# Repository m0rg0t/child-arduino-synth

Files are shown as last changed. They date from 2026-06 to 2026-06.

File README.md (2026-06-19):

# Child Buzzer Synth

A simple 7-key mini-piano toy for a child, built on an Arduino Nano with a
KY-006 passive buzzer. Seven keys play a C-major scale, a knob shifts the
octave, and a "squeeze both ends" gesture toggles a vibrato wobble.

Design spec: `docs/superpowers/specs/`. Wiring: `WIRING.md`. Enclosure models:
`stl/`.

## Firmware

- Sketch: `firmware/child_buzzer/child_buzzer.ino`
- Tunables (pins, note table, octaves, timings, vibrato, DEBUG):
  `firmware/child_buzzer/config.h`

### Flashing with the Arduino IDE

1. Open `firmware/child_buzzer/child_buzzer.ino`.
2. Tools → Board → **Arduino Nano**.
3. Tools → Processor → **ATmega328P** (or **"ATmega328P (Old Bootloader)"** for clones).
4. Tools → Port → your Nano's serial port.
5. Click **Upload (→)**.

### Flashing with arduino-cli

```bash
arduino-cli core install arduino:avr
arduino-cli compile --fqbn arduino:avr:nano firmware/child_buzzer
arduino-cli upload  --fqbn arduino:avr:nano:cpu=atmega328old -p /dev/cu.usbserial-XXXX firmware/child_buzzer
# Genuine Nanos (new bootloader): drop the :cpu=atmega328old suffix. Clone
# boards hang in avrdude sync without it.
```

## How to play

- **Press a key** → its note sounds while held (one note at a time; newest key wins).
- **Turn the knob** → shifts all keys up/down by octaves (deep ↔ squeaky) in Piano
  and Echo modes; controls tempo in Songs mode.

## Modes & gestures

Hold two keys for ~0.6 s to trigger a gesture (the held keys stay silent during the hold):

| Keys | Gesture | Feedback |
|---|---|---|
| 1 + 7 (ends) | toggle vibrato | rising chirp |
| 2 + 6 | toggle pentatonic scale | falling chirp  |
| 3 + 5 | next mode | 1–4 beeps = current mode |

Modes (announced by beep count when you cycle into them):

1. **Piano** — the classic 7-key C-major piano; knob = octave.
2. **FX** — each key is a sound effect: siren, laser, slide whistle, UFO,
   alarm, bird, robot.
3. **Songs** — each key plays a melody (key 1 = Twinkle Twinkle Little Star,
   key 2 = Mary Had a Little Lamb, key 3 = Ode to Joy, key 4 = a pop-ballad
   chorus hook, key 5 = the full pop ballad (verse → pre-chorus → chorus),
   key 6 = a hard-rock riff, key 7 = a stadium stomp-and-chant); knob = tempo;
   press the same key again to stop.
4. **Echo** — play something, pause 1.5 s, and the toy parrots it back.

Vibrato works in every mode; pentatonic changes the keyboard notes (Piano and
Echo). The knob sets the octave in Piano and Echo, and the tempo in Songs.

## Roadmap

- v2: line/aux audio output jack (design + parts list in the spec appendix).

## License

Released under the [MIT License](LICENSE) — free to use, modify, and build on
with attribution.

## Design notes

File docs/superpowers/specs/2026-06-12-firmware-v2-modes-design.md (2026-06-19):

# Child-buzzer firmware v2 — play modes

**Date:** 2026-06-12
**Status:** Implemented & verified on hardware (smoke test passed 2026-06-12; build 8138 B flash / 667 B SRAM)
**Builds on:** `docs/superpowers/specs/2026-06-03-child-buzzer-synth-design.md` (v1)

## Goal

Extend the 7-key mini-piano firmware with three new exclusive play modes (sound
effects, built-in songs, echo/parrot) plus a pentatonic scale toggle, all
switched by two-key hold combos in the spirit of the existing vibrato gesture.
No hardware changes: same 7 keys, octave knob, and KY-006 passive buzzer.

## Constraints (unchanged from v1)

- **Monophonic.** `tone()` owns the single hardware timer; one pitch at a time.
- **Integer-only math** in `loop()`; no floats.
- **Two-file split:** `config.h` holds all tunables/data, `child_buzzer.ino`
  holds all logic.
- ATmega328P: 32 KB flash, 2 KB SRAM. Song/FX data goes in `PROGMEM`.
- No automated tests; verification = `DEBUG` serial output + manual smoke test.

## Architecture

### The one-frequency contract

Every mode reduces to the contract the v1 piano already satisfies: *each tick,
produce one target frequency or −1 (silence).* All engines (piano,
FX sweep, song player, echo playback) feed the same final
`tone()`/`noTone()` write guarded by the `lastFreqWritten` dirty-flag.
Because the layering toggles (vibrato, pentatonic) act on that single
frequency path, they apply in every mode for free.

### Mode state machine

```c
enum Mode : uint8_t { MODE_PIANO, MODE_FX, MODE_SONG, MODE_ECHO };
```

- Default `MODE_PIANO` at power-up (no persistence across power cycles).
- Holding **keys 2+4** for `COMBO_HOLD_MS` cycles Piano → FX → Song → Echo →
  Piano. Entering mode *k* is announced with *k+1* short beeps (1 = Piano,
  4 = Echo). Beep announce may be briefly blocking, like v1 `chirp()`.
- Switching modes silences output and resets the engines (stops songs,
  clears the echo buffer, kills any running FX).

### Combo gestures (table-driven)

The v1 single-purpose `updateComboToggle` generalizes into a table of three
entries `{keyA, keyB, callback}`, each with its own edge-triggered hold state:

| Keys | Hold time | Action | Audio feedback |
|---|---|---|---|
| 0+6 (ends) | `COMBO_HOLD_MS` | toggle vibrato (v1, unchanged) | rising 2-beep chirp |
| 1+5 | `COMBO_HOLD_MS` | toggle pentatonic | falling 2-beep chirp |
| 2+4 | `COMBO_HOLD_MS` | cycle mode | N-beep mode announce |

While any combo pair is physically held, those keys are suppressed from note
playback. The v1 `suppressEnds` bool becomes a 7-bit suppression mask passed
to `activeNote()`.

### Orthogonal toggles

- **Vibrato (0+6):** v1 behavior, applies to the final frequency in any mode.
- **Pentatonic (1+5):** selects which 7-entry note table `noteFrequency()`
  reads. Second table in `config.h`: C-major pentatonic spanning into the
  next octave — `{262, 294, 330, 392, 440, 523, 587}` (C D E G A C′ D′).
  Octave doubling via `<< band` is unchanged. Affects piano/echo key input;
  songs and FX use their own pitch data and ignore it.

## Modes

### MODE_PIANO

Exactly v1 behavior (last-pressed-wins, knob = octave band), plus the new
toggles/combos above.

### MODE_FX — sound effects

Each key triggers one effect. All effects run on **one generic non-blocking
sweep engine**; an effect is a parameter row (stored in `config.h`):

```c
struct FxDef { uint16_t startHz, endHz; int16_t stepHz; uint8_t stepMs; uint8_t behavior; };
// behavior: FX_ONCE (play sweep once, then silence), FX_LOOP (wrap to start),
//           FX_PINGPONG (reverse at the ends)
```

Provisional key map (tunable):

| Key | Effect | Shape |
|-----|---|---|
| 0 | siren | slow PINGPONG, ~600–1200 Hz |
| 1 | laser zap | fast ONCE, high→low |
| 2 | slide whistle | medium ONCE, low→high |
| 3 | UFO warble | fast PINGPONG, narrow span |
| 4 | alarm | PINGPONG with step = full span (two-tone) |
| 5 | bird chirp | fast ONCE, short rising, retriggers while held |
| 6 | robot babble | LOOP with coarse steps across a wide span |

Effect sounds while the key is held; `FX_ONCE` runs to completion then goes
silent until re-press. Releasing the key silences immediately.
Last-pressed-wins applies, same as notes. The knob is unused in FX mode.

### MODE_SONG — built-in melodies

One melody per key, stored in `PROGMEM` as `{degree, duration}` pairs:

- `degree` = scale-degree index 0–6 into `NOTE_HZ` plus a small octave
  offset (packed in one byte; a sentinel value encodes a rest).
- `duration` = multiples of a base tick so the **knob controls tempo**
  (octave is meaningless mid-song; tempo is fun). Mapping: knob low = slow,
  high = fast, over a tunable BPM range.

Song list (key 0 → 6):

1. Twinkle Twinkle Little Star
2. Mary Had a Little Lamb
3. Ode to Joy
4. Pop-ballad chorus hook (see 2026-06-18-pop-ballad-song-design.md)
5. Full pop ballad — verse → pre-chorus → chorus
6. Hard-rock riff (the classic four-note figure)
7. Stadium stomp-and-chant hook (the stomp-stomp-clap rendered as low
   ~80–110 Hz thuds)

Note on the hard-rock riff: its intervals (0, +3, +5, +6 semitones)
are not playable from G in C major, but transposed to start on **B** they
land entirely on white keys: B–D–E | B–D–F–E | B–D–E | D–B. The
scale-degree encoding therefore needs no accidentals.

Interaction: pressing a key starts that song from the top; pressing a
*different* key switches songs; pressing the *same* key stops playback.
Playback is a non-blocking ticker in `loop()`. A song plays to its end and
stops (no looping).

### MODE_ECHO — record & parrot

The kid plays normally (full piano behavior, knob = octave, toggles apply)
while a recorder logs events:

```c
struct EchoEvent { uint8_t noteAndBand; uint16_t durationMs; uint16_t gapMs; };
// noteAndBand packs note index (low 3 bits) + octave band (next 2 bits)
// ECHO_MAX_EVENTS = 32  →  ~160 B of SRAM
```

- After `ECHO_SILENCE_MS` (default 1500 ms, tunable) with no key held and a
  non-empty buffer, the toy replays the recorded phrase (same notes,
  durations, and gaps, at the octave band captured per event... see below),
  then clears the buffer and is ready to record again.
- Recorded pitch: store the *final computed frequency band* alongside the
  note, i.e. record `{note, band}` at press time so knob twiddling during
  playback doesn't shift the parrot.
- Durations and gaps are clamped to `uint16_t` max (~65 s — far beyond toy
  attention spans).
- Buffer full → recording stops silently; the replay still happens at the
  silence timeout.
- Key presses during playback abort the replay and start a fresh recording.

## config.h additions (tunables/data only)

- `NOTE_HZ_PENTA[7]` second note table
- combo pair definitions + (existing) `COMBO_HOLD_MS`
- `FX_DEFS[7]` parameter rows + behavior enum constants
- `SONGS[7]` `PROGMEM` note tables + per-song lengths; tempo knob BPM range
- `ECHO_MAX_EVENTS`, `ECHO_SILENCE_MS`
- mode-announce beep pitch/duration

## child_buzzer.ino additions (logic only)

- `Mode` enum + mode cycle handling
- table-driven combo detector (replaces `updateComboToggle`)
- suppression mask in `activeNote()`
- FX sweep engine (one state struct: current Hz, direction, next-step time)
- song player ticker (current song, position, next-event time, tempo from knob)
- echo recorder + playback ticker
- `loop()` dispatches by mode to compute the tick's target frequency, then the
  existing shared vibrato + dirty-flag `tone()` write

## Error handling / edge cases

- Mode switch mid-sound: silence output, reset all engine state.
- Combo keys are suppressed as notes while held (existing v1 pattern).
- Blocking announce beeps (≤ ~500 ms) are acceptable, consistent with v1
  `chirp()`; `lastFreqWritten` is reset to −1 afterward.
- Echo buffer overflow: drop further events, keep what fits.
- All frequency math stays in `int32_t` intermediate / `uint16_t` result,
  as in v1.

## Verification (manual; no test harness)

Extend the `DEBUG` serial line with `mode=`. Smoke-test checklist:

1. Power-up → piano mode; v1 behaviors all intact (scale, octave knob,
   vibrato combo, debounce).
2. Hold 1+5 → falling chirp; keys now pentatonic; toggle back.
3. Hold 2+4 → 2 beeps → FX mode; each key produces its distinct effect;
   release silences; ONCE effects don't loop.
4. Hold 2+4 → 3 beeps → song mode; each key starts its song; same key stops;
   different key switches; knob audibly changes tempo; hard-rock
   riff recognizable.
5. Hold 2+4 → 4 beeps → echo mode; play a short phrase, wait ~1.5 s, hear it
   parroted back with timing; playing during replay interrupts it.
6. Hold 2+4 → 1 beep → back to piano.
7. Vibrato toggle works in every mode (wobbles songs/FX/echo playback).
8. Verify flash/SRAM usage in `arduino-cli compile` output stays comfortable
   (flash < 80%, SRAM < 50%).

## Out of scope

- Audio-jack line out (still deferred to v2 hardware, see v1 spec appendix).
- Mode persistence across power cycles (EEPROM) — not needed for a toy.
- Polyphony/arpeggio chords — cut during brainstorming.
- Games (Simon, follow-me teaching) — cut during brainstorming.

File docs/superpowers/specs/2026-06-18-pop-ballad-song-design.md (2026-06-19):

# Design: a pop ballad in song mode (two slots)

Date: 2026-06-18
Status: approved (design), pending on-device pitch verification

## Goal

Add a buzzer melody arrangement of a well-known pop ballad to **song mode**:

- **Key index 4** (the 5th physical key, README "key 5", currently *Frère
  Jacques*) → **full arrangement**: verse → pre-chorus → chorus, played once.
- **Key index 3** (the 4th physical key, README "key 4", currently *London
  Bridge*) → **short chorus hook** only.

*Frère Jacques* and *London Bridge* are displaced (removed). The other five
songs are unchanged.

## Constraints (from the existing hardware/firmware)

These are fixed by the toy and the song engine; the arrangement is built to fit
them, not the other way around:

1. **Monophonic.** One `tone()` voice → melody line only. No chords, no
   harmony, no accompaniment.
2. **White keys only.** A song note byte encodes a scale degree 0–6 into the
   major table `NOTE_HZ` (`C D E F G A B`) plus an octave band 0–3. There is no
   representation for sharps/flats. Any non-diatonic note in the source must be
   nudged to the nearest white key — the same approach already documented for
   the hard-rock riff song.
3. **No looping.** `songTick()` stops at the end of the table; a song plays once
   per press (press the same key again to stop early, a different key to
   switch).
4. **Knob = tempo.** `songTickMs()` maps the knob to 350 ms/tick (left, slow) …
   110 ms/tick (right, fast). A ballad sounds best toward the slow end. No
   per-song tempo storage — the player is tempo-agnostic.
5. **Data, not engine.** This is purely new `PROGMEM` tables + roster wiring.
   The song engine (`songTick`, `songLoadEvent`, `songNoteHz`, gaps, rests) is
   not modified.

## Musical approach

The ballad sits in a relative minor→major key pair (verse in a minor mode, the
chorus lifting to its relative major — one shared key signature). That maps
cleanly onto white keys by anchoring:

- **Verse** in **A natural minor** (`A B C D E F G` — all white keys),
- **Chorus** in its relative **C major** (`C D E F G A B` — all white keys).

So the bulk of the tune lands on white keys with no accidentals. The few
chromatic / raised-leading-tone moments get rounded to the nearest white key.
Octave placement: verse low (bands 0–1), pre-chorus rising, chorus up in bands
1–2 so the signature rising chorus hook reads clearly on the buzzer.

This is a **melodic reduction** — recognizable contour within the monophonic,
white-key, diatonic envelope — not a faithful reproduction of any recording.

## Data model (unchanged format)

Two new `PROGMEM` byte streams of `{note, duration}` pairs, same encoding as the
existing seven songs (`SN(deg, oct)`, `SONG_REST` for rests):

- `SONG_BALLAD[]` — verse + pre-chorus + chorus. Est. ~60–80 pairs
  (~120–160 B PROGMEM).
- `SONG_BALLAD_HOOK[]` — the chorus phrase only. Est. ~16–28 pairs.

Flash budget is a non-issue (32 KB part, current sketch is small; the v2 song
set added only ~250 B total).

## Files changed

- `firmware/child_buzzer/config.h`
  - Remove `SONG_LONDON[]` and `SONG_FRERE[]`.
  - Add `SONG_BALLAD_HOOK[]` (slot 3) and `SONG_BALLAD[]` (slot 4).
  - Update `SONGS[]`, `SONG_LEN[]`, and the per-key comments to the new roster.
- `README.md` — update the songs list (key 4 = pop-ballad chorus hook, key 5 =
  full pop ballad).
- `docs/superpowers/specs/2026-06-12-firmware-v2-modes-design.md` — update the
  song-list entries for keys 4 and 5 so the canonical reference stays accurate.

## Verification (empirical, on hardware)

There is no automated audio test; pitch correctness is verified by ear. The
Arduino is attached, so the loop is:

1. Transcribe → `arduino-cli compile --fqbn arduino:avr:nano`.
2. Flash with `cpu=atmega328old` (this board's old-bootloader requirement).
3. Cycle to song mode (hold keys 2+4 → 3 announce beeps).
4. Press key 4 (index 3) → short chorus hook; press key 5 (index 4) → full
   arrangement. Confirm both are recognizable; turn the knob to a slow tempo.
5. The user listens and flags any off notes; iterate on the tables and re-flash.

Acceptance: both keys play a recognizable rendition of the ballad, the full
version moves through verse → pre-chorus → chorus, tempo responds to the knob,
and the other five songs still play. Record the final compiled flash size.

## Out of scope

Chords/harmony (hardware can't), lyrics (note data only — no text reproduced),
looping, per-song tempo, and any change to the song engine or other modes.

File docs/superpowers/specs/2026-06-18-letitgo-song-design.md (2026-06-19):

# Design: "Let It Go" in song mode (two slots)

Date: 2026-06-18
Status: approved (design), pending on-device pitch verification

## Goal

Add a buzzer melody arrangement of *Let It Go* (Frozen) to **song mode**:

- **Key index 4** (the 5th physical key, README "key 5", currently *Frère
  Jacques*) → **full arrangement**: verse → pre-chorus → chorus, played once.
- **Key index 3** (the 4th physical key, README "key 4", currently *London
  Bridge*) → **short chorus hook** only.

*Frère Jacques* and *London Bridge* are displaced (removed). The other five
songs are unchanged.

## Constraints (from the existing hardware/firmware)

These are fixed by the toy and the song engine; the arrangement is built to fit
them, not the other way around:

1. **Monophonic.** One `tone()` voice → melody line only. No chords, no
   harmony, no accompaniment.
2. **White keys only.** A song note byte encodes a scale degree 0–6 into the
   major table `NOTE_HZ` (`C D E F G A B`) plus an octave band 0–3. There is no
   representation for sharps/flats. Any non-diatonic note in the source must be
   nudged to the nearest white key — the same approach already documented for
   *Smoke on the Water*.
3. **No looping.** `songTick()` stops at the end of the table; a song plays once
   per press (press the same key again to stop early, a different key to
   switch).
4. **Knob = tempo.** `songTickMs()` maps the knob to 350 ms/tick (left, slow) …
   110 ms/tick (right, fast). A ballad sounds best toward the slow end. No
   per-song tempo storage — the player is tempo-agnostic.
5. **Data, not engine.** This is purely new `PROGMEM` tables + roster wiring.
   The song engine (`songTick`, `songLoadEvent`, `songNoteHz`, gaps, rests) is
   not modified.

## Musical approach

*Let It Go* sits in a relative minor→major key pair (verse in a minor mode, the
chorus lifting to its relative major — one shared key signature). That maps
cleanly onto white keys by anchoring:

- **Verse** in **A natural minor** (`A B C D E F G` — all white keys),
- **Chorus** in its relative **C major** (`C D E F G A B` — all white keys).

So the bulk of the tune lands on white keys with no accidentals. The few
chromatic / raised-leading-tone moments get rounded to the nearest white key.
Octave placement: verse low (bands 0–1), pre-chorus rising, chorus up in bands
1–2 so the signature rising "let it go" sequence reads clearly on the buzzer.

This is a **melodic reduction** — recognizable contour within the monophonic,
white-key, diatonic envelope — not a faithful reproduction of the recording.

## Data model (unchanged format)

Two new `PROGMEM` byte streams of `{note, duration}` pairs, same encoding as the
existing seven songs (`SN(deg, oct)`, `SONG_REST` for rests):

- `SONG_LETITGO[]` — verse + pre-chorus + chorus. Est. ~60–80 pairs
  (~120–160 B PROGMEM).
- `SONG_LETITGO_HOOK[]` — the chorus phrase only. Est. ~16–28 pairs.

Flash budget is a non-issue (32 KB part, current sketch is small; the v2 song
set added only ~250 B total).

## Files changed

- `firmware/child_buzzer/config.h`
  - Remove `SONG_LONDON[]` and `SONG_FRERE[]`.
  - Add `SONG_LETITGO_HOOK[]` (slot 3) and `SONG_LETITGO[]` (slot 4).
  - Update `SONGS[]`, `SONG_LEN[]`, and the per-key comments to the new roster.
- `README.md` — update the songs list (key 4 = Let It Go hook, key 5 = Let It
  Go full).
- `docs/superpowers/specs/2026-06-12-firmware-v2-modes-design.md` — update the
  song-list entries for keys 4 and 5 so the canonical reference stays accurate.

## Verification (empirical, on hardware)

There is no automated audio test; pitch correctness is verified by ear. The
Arduino is attached, so the loop is:

1. Transcribe → `arduino-cli compile --fqbn arduino:avr:nano`.
2. Flash with `cpu=atmega328old` (this board's old-bootloader requirement).
3. Cycle to song mode (hold keys 2+4 → 3 announce beeps).
4. Press key 4 (index 3) → short chorus hook; press key 5 (index 4) → full
   arrangement. Confirm both are recognizable; turn the knob to a slow tempo.
5. The user listens and flags any off notes; iterate on the tables and re-flash.

Acceptance: both keys play a recognizable *Let It Go*, the full version moves
through verse → pre-chorus → chorus, tempo responds to the knob, and the other
five songs still play. Record the final compiled flash size.

## Out of scope

Chords/harmony (hardware can't), lyrics (note data only — no text reproduced),
looping, per-song tempo, and any change to the song engine or other modes.

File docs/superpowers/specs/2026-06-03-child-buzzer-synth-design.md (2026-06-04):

# Child Buzzer Synth — Design Spec

**Date:** 2026-06-03
**Status:** Approved (design); implementation pending
**v1 scope:** mini-piano + octave knob + vibrato. The line/aux audio jack is
**deferred to a later version** — its design is preserved in the appendix.

## Overview

A simple, sturdy mini-piano toy for a child. Seven keyboard switches play the
notes of a one-octave C-major scale through a KY-006 passive buzzer. A rotary
knob shifts the whole keyboard up or down by octaves (deep ↔ squeaky). A
software "squeeze both ends" gesture toggles a vibrato (pitch-wobble) effect.

A passive line/aux audio jack is planned for a later version (see appendix); v1
ships with the on-board buzzer only.

## Goals

- Intuitive for a small child: press a key → hear a note; turn the knob → pitch
  changes; no menus or screens.
- Pleasant, musical output (diatonic scale, in tune).
- Buildable from exactly the parts on hand — no extra components required.
- Firmware that is easy to re-tune (notes, octaves, timings, vibrato) without
  editing logic.

## Hardware / Bill of Materials

Exactly the parts already specified — nothing extra for v1:

| Qty | Part | Notes |
|----:|---|---|
| 1 | Arduino Nano | The brain |
| 7 | Keyboard switches (mechanical key switches) | One per piano key |
| 1 | Rotary angle sensor (analog potentiometer) | Octave knob — NOT an encoder |
| 1 | KY-006 passive piezo buzzer | Driven by `tone()` square wave |

The line/aux audio jack and its passives are listed in the appendix (deferred).

### Pin map

| Signal | Pin | Mode | Wiring |
|---|-----|---|---|
| Key 1 (C, lowest) | D2 | `INPUT_PULLUP` | switch other side → GND |
| Key 2 (D) | D3 | `INPUT_PULLUP` | switch → GND |
| Key 3 (E) | D4 | `INPUT_PULLUP` | switch → GND |
| Key 4 (F) | D5 | `INPUT_PULLUP` | switch → GND |
| Key 5 (G) | D6 | `INPUT_PULLUP` | switch → GND |
| Key 6 (A) | D7 | `INPUT_PULLUP` | switch → GND |
| Key 7 (B, highest) | D8 | `INPUT_PULLUP` | switch → GND |
| Buzzer | D9 | `OUTPUT` (`tone`) | KY-006 signal pin; GND to GND |
| Octave knob | A0 | analog in | pot wiper → A0; ends → 5V and GND |

`INPUT_PULLUP` means each switch only needs to connect its pin to GND when
pressed — no external resistors. A pressed key therefore reads `LOW`.

> **Audio jack:** deferred to a later version. The full circuit and parts list
> live in the appendix so the v1 build stays focused on the buzzer.

## Behavior

### 1. Mini-piano (free play)

- The 7 keys map to one octave of the **C-major scale**:
  `C D E F G A B` (do-re-mi-fa-sol-la-ti).
- **Sound while held:** pressing a key starts its note; releasing stops it.
- **Monophonic, last-pressed-wins:** only one note sounds at a time (single tone
  timer). The most recently pressed key that is still held is the one that
  sounds. When it is released, sound falls back to another currently-held key
  (most recent of those). When no key is held, the buzzer is silent (`noTone()`).
- Each key is **debounced** (~5 ms stable-state filter) to reject contact bounce.

### 2. Octave knob

- `analogRead(A0)` (0–1023) is mapped to **4 octave bands** (index 0–3):
  `band = (raw * 4) / 1024` → 0,1,2,3 across the knob's travel.
- Octave shift is applied by doubling frequency: `freq = noteHz[key] << band`.
  Doubling is exact and avoids floating-point math.
- Re-read every loop, so turning the knob **while holding a key** slides the
  pitch by whole octaves live.
- Base octave is C4: band 0 = C4 (262 Hz) … band 3 ≈ B7 (~3951 Hz) — squarely in
  the piezo's loudest range so even the lowest keys are clearly audible.

### 3. Vibrato toggle (software combo)

- **Gesture:** hold the **lowest + highest keys together** (Key 1 + Key 7) for
  **~600 ms** to toggle vibrato on/off.
- **Edge-triggered:** the toggle fires once when the combo is recognized, then
  will not fire again until both keys are released. This prevents rapid
  on/off flapping while the combo is held.
- During the combo, those two keys' **notes are suppressed** (no C/B note plays).
- On toggle, play a short **confirmation chirp** (e.g. two quick beeps) so the
  child gets feedback even though there is no screen.

### 4. Vibrato effect

- When **on**, the sounding note's pitch wobbles **±~4%** around the base note at
  **~6 Hz**.
- Implemented by re-calling `tone(BUZZER, modulatedFreq)` on a fixed update tick
  (e.g. every ~10 ms). `tone()` keeps the buzzer running on its timer; we just
  nudge the frequency on schedule.
- The wobble shape comes from a small **lookup table** (or triangle wave) to
  avoid slow floating-point `sin()` in the loop.
- When **off**, the note plays at a steady frequency.

## Firmware architecture

Approach A — single sketch + a hardware/config header:

- **`child_buzzer.ino`** — all logic:
  - `setup()` — configure pin modes.
  - `loop()` — orchestrate: read octave band, scan keys, detect combo, pick the
    active note, apply vibrato, drive `tone()` / `noTone()`.
  - `scanKeys()` — per-key debounce; maintain pressed state + press order.
  - `activeNoteIndex()` — apply last-pressed-wins to choose the sounding key
    (or none).
  - `readOctaveBand()` — knob → octave band 0–3.
  - `updateVibratoCombo()` — detect the both-ends hold, edge-triggered toggle,
    confirmation chirp.
  - `applyVibrato(baseFreq)` — return modulated frequency from the LUT when
    vibrato is on, else `baseFreq`.
- **`config.h`** — everything tweakable without touching logic:
  - Pin numbers (keys, buzzer, knob).
  - `noteHz[7]` — C-major base frequencies (octave 0 / C4).
  - `OCTAVE_BANDS` (default 4).
  - `VIBRATO_DEPTH_PCT` (~4), `VIBRATO_RATE_HZ` (~6), vibrato update interval.
  - `DEBOUNCE_MS` (~5), `COMBO_HOLD_MS` (~600).
  - `DEBUG` flag.
- **`WIRING.md`** — pin-by-pin connection table incl. the jack RC network.
- **`README.md`** — what it is + how to flash (Arduino IDE: select the Nano
  board + port, then upload).
- Existing **`stl/`** models and **`screenshoots/`** render are left untouched.

## Verification

Arduino firmware has no host test harness here; verification is debug output +
a manual smoke test.

- **`DEBUG` flag** prints to Serial: detected active key, octave band, computed
  frequency, and vibrato on/off state — so behavior is observable, not guessed.
- **Manual smoke-test checklist:**
  1. Each of the 7 keys sounds its own ascending note; releasing silences it.
  2. Pressing a new key while holding another switches to the new note;
     releasing it falls back to the still-held key.
  3. Turning the knob across its range shifts all keys through 4 octave bands.
  4. Holding both end keys ~600 ms plays the confirmation chirp and toggles
     vibrato; a single toggle per gesture (no flapping).
  5. With vibrato on, a held note audibly wobbles; with it off, the note is
     steady.

## Out of scope (possible future work)

- **Line/aux audio jack** — designed and parts-listed below; deferred to v2.
- Polyphony (would need more than the single tone timer).
- Selectable scales / instruments via the knob.
- Hardware vibrato switch or auto-mute switched jack.
- On-board amplifier for direct, loud headphone drive.

## Open tunables (decide during build by ear)

- Exact vibrato depth/rate (start ±4% / 6 Hz).
- Octave band base/range (start C4 → B7, 4 bands).
- Confirmation chirp pattern.

## Appendix — Line/aux audio jack (deferred to v2)

Passive add-on that hangs in parallel off the D9 tone signal — no firmware
change. Lets the toy feed powered speakers / an amp / aux-in while the on-board
buzzer keeps playing.

```
D9 ──[ ~1 kΩ ]──┬──[ 10 µF + ]──┬── Jack TIP ─┐
                │   (+ to D9)    │             ├─ tied together (mono → both ears)
              [10 kΩ]            └── Jack RING ┘
                │
               GND ───────────────────────────── Jack SLEEVE
```

- Coupling cap blocks the square wave's DC offset (no DC through the speaker).
- Series + shunt resistors attenuate the 5 V swing toward a safe line level and
  gently low-pass the square wave. Raise the series resistor to lower the level.
- Tip + ring tied so the mono tone reaches both channels.

### Parts to buy (jack add-on)

| # | Part | Spec to search for | Qty | Notes |
|---|---|---|----:|---|
| 1 | 3.5 mm stereo panel-mount jack (TRS, female) | "3.5mm stereo panel mount jack threaded nut" / PJ-392 | 1 | Threaded barrel + nut to screw into the enclosure hole. Confirm thread matches the hole (commonly 6 mm). |
| 2 | Coupling capacitor 10 µF | "10µF 25V electrolytic" (+ toward D9) **or** 1–10 µF film (non-polarized) | 1 | Rating ≥16 V. |
| 3 | Series resistor 1 kΩ | "1kΩ 1/4W 5%" | 1 | Current limit / attenuation. |
| 4 | Shunt resistor 10 kΩ | "10kΩ 1/4W 5%" | 1 | Sets DC level / divider to ground. |
| 5 | Hookup wire + heat-shrink (optional) | "22 AWG hookup wire", "2mm heat shrink" | — | Tidy solder joints to the jack lugs. |

Open tunable: jack attenuation — start 1 kΩ series / 10 kΩ shunt / 10 µF cap,
adjust series R by ear.

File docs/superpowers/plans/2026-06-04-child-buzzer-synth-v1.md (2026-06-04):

# Child Buzzer Synth v1 — Implementation Plan

> **For agentic workers:** REQUIRED SUB-SKILL: Use superpowers:subagent-driven-development (recommended) or superpowers:executing-plans to implement this plan task-by-task. Steps use checkbox (`- [ ]`) syntax for tracking.

**Goal:** Build the firmware for a 7-key mini-piano toy on an Arduino Nano: keys play a C-major scale through a KY-006 passive buzzer, a knob shifts the octave, and a "squeeze both ends" gesture toggles a vibrato wobble.

**Architecture:** A single Arduino sketch (`child_buzzer.ino`) with all hardware logic, plus a `config.h` holding every tunable (pins, note table, octave count, timings, vibrato, DEBUG). No external libraries — only the built-in `tone()`/`noTone()`, `digitalRead`, `analogRead`, `millis`. Monophonic output (one tone timer) with last-pressed-wins note selection. Verification is by clean compile + a manual hardware smoke test (no host test harness, per the approved spec).

**Tech Stack:** Arduino Nano (ATmega328P), Arduino C++, `tone()` square-wave output, internal pull-ups for switches, analog read for the potentiometer.

---

## File Structure

```
child-buzzer/                       (existing git repo)
├── firmware/
│   └── child_buzzer/               (Arduino sketch folder — name matches .ino)
│       ├── child_buzzer.ino        (all logic: setup, loop, keys, octave, vibrato)
│       └── config.h                (pins, note table, octaves, timings, vibrato, DEBUG)
├── WIRING.md                       (pin-by-pin connection guide)
├── README.md                       (what it is + how to flash + how to play)
├── docs/superpowers/...            (spec + this plan)
├── stl/                            (existing 3D models — untouched)
└── screenshoots/                   (existing render — untouched)
```

Responsibilities:
- **`config.h`** — the only file you edit to re-tune behavior. Pure constants.
- **`child_buzzer.ino`** — reads hardware, decides the active note, drives the buzzer.
- **`WIRING.md` / `README.md`** — build + usage docs.

## Compile verification (used by every code task)

Two options. Use whichever you have.

- **arduino-cli** (one-time setup `arduino-cli core install arduino:avr`):
  ```bash
  arduino-cli compile --fqbn arduino:avr:nano firmware/child_buzzer
  ```
  Expected: ends with `Sketch uses NNNN bytes ... Global variables use ...` and exit code 0. For old-bootloader clones the upload step later uses `--fqbn arduino:avr:nano:cpu=atmega328old`; the compile FQBN above is fine either way.
- **Arduino IDE:** open `firmware/child_buzzer/child_buzzer.ino`, click **Verify (✓)**. Expected: "Done compiling." with no errors.

---

### Task 1: Sketch scaffold — `config.h` + minimal compiling sketch

**Files:**
- Create: `firmware/child_buzzer/config.h`
- Create: `firmware/child_buzzer/child_buzzer.ino`

- [ ] **Step 1: Create `config.h` with all tunables**

```cpp
#ifndef CONFIG_H
#define CONFIG_H

#include <Arduino.h>

// ---- Pins ----
// 7 keyboard switches, lowest (C) -> highest (B). Each switch wired to GND,
// read with INPUT_PULLUP, so a pressed key reads LOW.
const uint8_t KEY_PINS[7] = { 2, 3, 4, 5, 6, 7, 8 };
const uint8_t BUZZER_PIN  = 9;     // KY-006 passive buzzer signal pin
const uint8_t KNOB_PIN    = A0;    // rotary angle sensor (potentiometer) wiper

// ---- Notes ----
// Base frequencies (Hz) for octave band 0 = C-major scale starting at C4.
// Index 0..6 = C D E F G A B. Higher octave bands multiply by 2 per band.
const uint16_t NOTE_HZ[7]  = { 262, 294, 330, 349, 392, 440, 494 };
const uint8_t  OCTAVE_BANDS = 4;   // knob selects band 0..3  (C4 .. ~B7)

// ---- Timing ----
const uint16_t DEBOUNCE_MS   = 5;    // per-key debounce window
const uint16_t COMBO_HOLD_MS = 600;  // hold both end keys this long to toggle vibrato

// ---- Vibrato ----
const uint16_t VIBRATO_DEPTH_PERMILLE = 40;  // +/-4.0% pitch wobble
const uint16_t VIBRATO_UPDATE_MS      = 10;  // how often to nudge the pitch
// 16 LUT steps * 10 ms = 160 ms per cycle ~= 6.25 Hz wobble.

// ---- Debug ----
#define DEBUG 0   // set to 1 to print state over Serial @115200

#endif // CONFIG_H
```

- [ ] **Step 2: Create minimal `child_buzzer.ino`**

```cpp
#include "config.h"

void setup() {
  for (uint8_t i = 0; i < 7; i++) {
    pinMode(KEY_PINS[i], INPUT_PULLUP);
  }
  pinMode(BUZZER_PIN, OUTPUT);
#if DEBUG
  Serial.begin(115200);
#endif
}

void loop() {
  // Behavior is added in later tasks.
}
```

- [ ] **Step 3: Verify it compiles**

Run: `arduino-cli compile --fqbn arduino:avr:nano firmware/child_buzzer` (or IDE Verify)
Expected: compiles cleanly, exit code 0.

- [ ] **Step 4: Commit**

```bash
git add firmware/child_buzzer/config.h firmware/child_buzzer/child_buzzer.ino
git commit -m "feat(fw): scaffold sketch with pin setup and tunable config.h"
```

---

### Task 2: Playable mono piano — keys, debounce, last-pressed-wins, octave knob

This is the mid-build hardware checkpoint: after this task you can flash it and play 7 notes across 4 octaves. No vibrato yet.

**Files:**
- Modify: `firmware/child_buzzer/child_buzzer.ino` (replace entire file)

- [ ] **Step 1: Replace `child_buzzer.ino` with the mono-piano version**

```cpp
#include "config.h"

// ---- Per-key debounce + press-order state ----
bool     keyHeld[7]      = { false, false, false, false, false, false, false };
bool     lastReading[7]  = { false, false, false, false, false, false, false };
uint32_t lastChangeMs[7] = { 0, 0, 0, 0, 0, 0, 0 };
uint32_t pressOrder[7]   = { 0, 0, 0, 0, 0, 0, 0 };  // 0 = not held; larger = newer
uint32_t pressCounter    = 0;

int      lastFreqWritten = -1;  // -1 means noTone() is currently active

void setup() {
  for (uint8_t i = 0; i < 7; i++) {
    pinMode(KEY_PINS[i], INPUT_PULLUP);
  }
  pinMode(BUZZER_PIN, OUTPUT);
#if DEBUG
  Serial.begin(115200);
#endif
}

// Debounce one key and update keyHeld[i] + pressOrder[i].
void debounceKey(uint8_t i, uint32_t now) {
  bool reading = (digitalRead(KEY_PINS[i]) == LOW);  // pressed shorts pin to GND
  if (reading != lastReading[i]) {
    lastReading[i] = reading;
    lastChangeMs[i] = now;
  }
  if (now - lastChangeMs[i] >= DEBOUNCE_MS && reading != keyHeld[i]) {
    keyHeld[i] = reading;
    pressOrder[i] = reading ? ++pressCounter : 0;  // newest press wins; 0 on release
  }
}

// Most-recently-pressed key still held (0..6), or -1 if none.
// When suppressEnds is true, keys 0 and 6 are ignored (used during the combo).
int activeNote(bool suppressEnds) {
  int best = -1;
  uint32_t bestOrder = 0;
  for (uint8_t i = 0; i < 7; i++) {
    if (!keyHeld[i]) continue;
    if (suppressEnds && (i == 0 || i == 6)) continue;
    if (pressOrder[i] > bestOrder) {
      bestOrder = pressOrder[i];
      best = i;
    }
  }
  return best;
}

// Frequency for a note index at an octave band (doubling per band; exact).
uint16_t noteFrequency(int noteIndex, uint8_t band) {
  return (uint16_t)(NOTE_HZ[noteIndex] << band);
}

// Knob (0..1023) -> octave band 0..OCTAVE_BANDS-1.
uint8_t readOctaveBand() {
  int raw = analogRead(KNOB_PIN);
  uint8_t band = (uint8_t)((uint32_t)raw * OCTAVE_BANDS / 1024);
  if (band >= OCTAVE_BANDS) band = OCTAVE_BANDS - 1;
  return band;
}

void loop() {
  uint32_t now = millis();

  for (uint8_t i = 0; i < 7; i++) {
    debounceKey(i, now);
  }

  int note = activeNote(false);
  uint8_t band = readOctaveBand();

  int freq = (note < 0) ? -1 : (int)noteFrequency(note, band);

  if (freq != lastFreqWritten) {
    if (freq < 0) {
      noTone(BUZZER_PIN);
    } else {
      tone(BUZZER_PIN, (unsigned int)freq);
    }
    lastFreqWritten = freq;
  }
}
```

- [ ] **Step 2: Verify it compiles**

Run: `arduino-cli compile --fqbn arduino:avr:nano firmware/child_buzzer` (or IDE Verify)
Expected: compiles cleanly, exit code 0.

- [ ] **Step 3: (Optional) Flash and spot-check on hardware**

Flash to the Nano. Expected: each key plays an ascending note while held; releasing silences it; pressing a second key takes over and releasing it falls back to the still-held key; turning the knob shifts all notes across octaves.

- [ ] **Step 4: Commit**

```bash
git add firmware/child_buzzer/child_buzzer.ino
git commit -m "feat(fw): playable mono piano — debounced keys, last-pressed-wins, octave knob"
```

---

### Task 3: Vibrato effect + "squeeze both ends" combo toggle + confirmation chirp

**Files:**
- Modify: `firmware/child_buzzer/child_buzzer.ino` (replace entire file)

- [ ] **Step 1: Replace `child_buzzer.ino` with the final version**

```cpp
#include "config.h"

// ---- Per-key debounce + press-order state ----
bool     keyHeld[7]      = { false, false, false, false, false, false, false };
bool     lastReading[7]  = { false, false, false, false, false, false, false };
uint32_t lastChangeMs[7] = { 0, 0, 0, 0, 0, 0, 0 };
uint32_t pressOrder[7]   = { 0, 0, 0, 0, 0, 0, 0 };  // 0 = not held; larger = newer
uint32_t pressCounter    = 0;

int      lastFreqWritten = -1;  // -1 means noTone() is currently active

// ---- Vibrato wobble shape: one sine cycle, 16 steps, scaled to +/-1000 ----
const uint8_t VIBRATO_STEPS = 16;
const int16_t VIBRATO_LUT[VIBRATO_STEPS] = {
     0,   383,   707,   924,  1000,   924,   707,   383,
     0,  -383,  -707,  -924, -1000,  -924,  -707,  -383
};

bool     vibratoOn      = false;
uint8_t  vibratoPhase   = 0;
uint32_t lastVibratoMs  = 0;

// ---- Combo (both end keys held) toggle state ----
bool     comboActive    = false;  // both ends currently held (candidate window)
bool     comboFired     = false;  // already toggled during this hold
uint32_t comboStartMs   = 0;

void setup() {
  for (uint8_t i = 0; i < 7; i++) {
    pinMode(KEY_PINS[i], INPUT_PULLUP);
  }
  pinMode(BUZZER_PIN, OUTPUT);
#if DEBUG
  Serial.begin(115200);
#endif
}

// Debounce one key and update keyHeld[i] + pressOrder[i].
void debounceKey(uint8_t i, uint32_t now) {
  bool reading = (digitalRead(KEY_PINS[i]) == LOW);  // pressed shorts pin to GND
  if (reading != lastReading[i]) {
    lastReading[i] = reading;
    lastChangeMs[i] = now;
  }
  if (now - lastChangeMs[i] >= DEBOUNCE_MS && reading != keyHeld[i]) {
    keyHeld[i] = reading;
    pressOrder[i] = reading ? ++pressCounter : 0;  // newest press wins; 0 on release
  }
}

// Most-recently-pressed key still held (0..6), or -1 if none.
// When suppressEnds is true, keys 0 and 6 are ignored (used during the combo).
int activeNote(bool suppressEnds) {
  int best = -1;
  uint32_t bestOrder = 0;
  for (uint8_t i = 0; i < 7; i++) {
    if (!keyHeld[i]) continue;
    if (suppressEnds && (i == 0 || i == 6)) continue;
    if (pressOrder[i] > bestOrder) {
      bestOrder = pressOrder[i];
      best = i;
    }
  }
  return best;
}

// Frequency for a note index at an octave band (doubling per band; exact).
uint16_t noteFrequency(int noteIndex, uint8_t band) {
  return (uint16_t)(NOTE_HZ[noteIndex] << band);
}

// Knob (0..1023) -> octave band 0..OCTAVE_BANDS-1.
uint8_t readOctaveBand() {
  int raw = analogRead(KNOB_PIN);
  uint8_t band = (uint8_t)((uint32_t)raw * OCTAVE_BANDS / 1024);
  if (band >= OCTAVE_BANDS) band = OCTAVE_BANDS - 1;
  return band;
}

// Apply the current vibrato phase to a base frequency.
// modulated = base * (1000 + depth_permille * lut/1000) / 1000
uint16_t applyVibrato(uint16_t baseFreq) {
  int16_t lut = VIBRATO_LUT[vibratoPhase];                 // -1000..1000
  int32_t factor = 1000 + (int32_t)VIBRATO_DEPTH_PERMILLE * lut / 1000;
  return (uint16_t)((int32_t)baseFreq * factor / 1000);
}

// Two quick beeps confirming a vibrato toggle. Briefly blocking (~220 ms) — fine
// for a toy; the combo is being held so no note should be sounding anyway.
void chirp() {
  tone(BUZZER_PIN, 1568); delay(70);   // ~G6
  noTone(BUZZER_PIN);     delay(40);
  tone(BUZZER_PIN, 2093); delay(70);   // ~C7
  noTone(BUZZER_PIN);     delay(40);
  lastFreqWritten = -1;                // force the next loop to re-assert the tone
}

// Detect the "both end keys held for COMBO_HOLD_MS" gesture and toggle vibrato
// exactly once per hold (edge-triggered).
void updateComboToggle(uint32_t now) {
  bool bothEnds = keyHeld[0] && keyHeld[6];
  if (bothEnds) {
    if (!comboActive) {
      comboActive = true;
      comboFired = false;
      comboStartMs = now;
    } else if (!comboFired && (now - comboStartMs >= COMBO_HOLD_MS)) {
      comboFired = true;
      vibratoOn = !vibratoOn;
      chirp();
    }
  } else {
    comboActive = false;
    comboFired = false;
  }
}

void loop() {
  uint32_t now = millis();

  for (uint8_t i = 0; i < 7; i++) {
    debounceKey(i, now);
  }

  updateComboToggle(now);

  // Advance the vibrato wobble on its own tick.
  if (vibratoOn && (now - lastVibratoMs >= VIBRATO_UPDATE_MS)) {
    lastVibratoMs = now;
    vibratoPhase = (vibratoPhase + 1) % VIBRATO_STEPS;
  }

  bool suppressEnds = (keyHeld[0] && keyHeld[6]);
  int note = activeNote(suppressEnds);
  uint8_t band = readOctaveBand();

  int freq;
  if (note < 0) {
    freq = -1;
  } else {
    uint16_t base = noteFrequency(note, band);
    freq = vibratoOn ? applyVibrato(base) : base;
  }

  if (freq != lastFreqWritten) {
    if (freq < 0) {
      noTone(BUZZER_PIN);
    } else {
      tone(BUZZER_PIN, (unsigned int)freq);
    }
    lastFreqWritten = freq;
  }

#if DEBUG
  static uint32_t lastDbg = 0;
  if (now - lastDbg >= 200) {
    lastDbg = now;
    Serial.print(F("note=")); Serial.print(note);
    Serial.print(F(" band=")); Serial.print(band);
    Serial.print(F(" freq=")); Serial.print(freq);
    Serial.print(F(" vib=")); Serial.println(vibratoOn ? 1 : 0);
  }
#endif
}
```

- [ ] **Step 2: Verify it compiles**

Run: `arduino-cli compile --fqbn arduino:avr:nano firmware/child_buzzer` (or IDE Verify)
Expected: compiles cleanly, exit code 0.

- [ ] **Step 3: Commit**

```bash
git add firmware/child_buzzer/child_buzzer.ino
git commit -m "feat(fw): add vibrato wobble + squeeze-both-ends toggle with chirp + DEBUG"
```

---

### Task 4: Wiring guide

**Files:**
- Create: `WIRING.md`

- [ ] **Step 1: Create `WIRING.md`**

```markdown
# Wiring — Child Buzzer Synth (v1)

Board: Arduino Nano. All switches use the internal pull-ups, so a pressed key
just connects its pin to GND (reads LOW). No external resistors needed.

## Keyboard switches (7)

| Key | Note | Nano pin | Switch wiring |
|-----|------|----------|---------------|
| 1 (lowest)  | C | D2 | one leg → D2, other leg → GND |
| 2 | D | D3 | one leg → D3, other leg → GND |
| 3 | E | D4 | one leg → D4, other leg → GND |
| 4 | F | D5 | one leg → D5, other leg → GND |
| 5 | G | D6 | one leg → D6, other leg → GND |
| 6 | A | D7 | one leg → D7, other leg → GND |
| 7 (highest) | B | D8 | one leg → D8, other leg → GND |

Tie every switch's "other leg" to a shared GND rail.

## KY-006 passive buzzer

| KY-006 pin | Connect to |
|------------|------------|
| S (signal) | D9 |
| − (GND)    | GND |
| middle (+) | leave unconnected (passive module; varies by board) |

## Rotary angle sensor (potentiometer) — octave knob

| Pot pin | Connect to |
|---------|------------|
| one outer leg   | 5V |
| other outer leg | GND |
| wiper (middle)  | A0 |

If the knob shifts pitch the "wrong" way, swap the two outer legs (5V ↔ GND).

## Power & ground

Power the Nano over USB (or regulated 5V). All grounds (switches, buzzer, pot)
share one common GND.

## How to play

- Press a key → its note sounds while held (one note at a time, newest wins).
- Turn the knob → shifts all keys across 4 octaves (deep ↔ squeaky).
- Hold the lowest + highest keys together (~0.6 s) → toggles vibrato; a two-beep
  chirp confirms.
```

- [ ] **Step 2: Commit**

```bash
git add WIRING.md
git commit -m "docs: add pin-by-pin wiring guide"
```

---

### Task 5: Project README

**Files:**
- Create: `README.md`

- [ ] **Step 1: Create `README.md`**

````markdown
# Child Buzzer Synth

A simple 7-key mini-piano toy for a child, built on an Arduino Nano with a
KY-006 passive buzzer. Seven keys play a C-major scale, a knob shifts the
octave, and a "squeeze both ends" gesture toggles a vibrato wobble.

Design spec: `docs/superpowers/specs/`. Wiring: `WIRING.md`. Enclosure models:
`stl/`.

## Firmware

- Sketch: `firmware/child_buzzer/child_buzzer.ino`
- Tunables (pins, note table, octaves, timings, vibrato, DEBUG):
  `firmware/child_buzzer/config.h`

### Flashing with the Arduino IDE

1. Open `firmware/child_buzzer/child_buzzer.ino`.
2. Tools → Board → **Arduino Nano**.
3. Tools → Processor → **ATmega328P** (or **"ATmega328P (Old Bootloader)"** for clones).
4. Tools → Port → your Nano's serial port.
5. Click **Upload (→)**.

### Flashing with arduino-cli

```bash
arduino-cli core install arduino:avr
arduino-cli compile --fqbn arduino:avr:nano firmware/child_buzzer
arduino-cli upload  --fqbn arduino:avr:nano -p /dev/cu.usbserial-XXXX firmware/child_buzzer
# Old-bootloader clones: add :cpu=atmega328old to the FQBN.
```

## How to play

- **Press a key** → its note sounds while held (one note at a time; newest key wins).
- **Turn the knob** → moves all keys up/down by octaves (deep ↔ squeaky).
- **Hold lowest + highest keys together (~0.6 s)** → toggles vibrato on/off
  (two-beep chirp confirms).

## Roadmap

- v2: line/aux audio output jack (design + parts list in the spec appendix).
````

- [ ] **Step 2: Commit**

```bash
git add README.md
git commit -m "docs: add project README with flashing and play instructions"
```

---

### Task 6: Hardware smoke test

No automated tests (per the approved spec) — this is the acceptance check. Flash
`firmware/child_buzzer` to the Nano wired per `WIRING.md`, then verify each item.

- [ ] **Step 1: Flash the final firmware to the Nano**

```bash
arduino-cli upload --fqbn arduino:avr:nano -p /dev/cu.usbserial-XXXX firmware/child_buzzer
```
(or Upload from the Arduino IDE)

- [ ] **Step 2: Run the smoke-test checklist (by ear)**

  - [ ] Each of the 7 keys sounds its own ascending note; releasing silences it.
  - [ ] Pressing a new key while holding another switches to the new note; releasing it falls back to the still-held key.
  - [ ] Turning the knob across its range steps all keys through 4 octave bands (low → high).
  - [ ] Holding both end keys ~0.6 s plays the two-beep chirp and toggles vibrato; only one toggle per hold (no rapid flapping).
  - [ ] With vibrato on, a held note audibly wobbles; with it off, the note is steady.
  - [ ] (Optional) Set `DEBUG 1` in `config.h`, re-flash, open Serial Monitor @115200, and confirm `note/band/freq/vib` track what you do. Set back to `0` after.

- [ ] **Step 3: Record the result**

If anything fails, debug with `DEBUG 1` before changing logic. When all pass, the
v1 build is done.

---

## Self-Review

**Spec coverage:**
- Mini-piano, 7 keys = C-major, sound-while-held → Task 2 (`debounceKey`, `activeNote`, `loop`).
- Monophonic last-pressed-wins → Task 2 (`pressOrder` + `activeNote`).
- ~5 ms debounce → Task 2 (`debounceKey`, `DEBOUNCE_MS`).
- Octave knob → 4 bands, live shift, doubling frequency → Task 2 (`readOctaveBand`, `noteFrequency`).
- Vibrato toggle via both-ends ~600 ms, edge-triggered, ends suppressed, confirmation chirp → Task 3 (`updateComboToggle`, `chirp`, `activeNote(suppressEnds)`).
- Vibrato effect ±4% / ~6 Hz via LUT, no float in loop → Task 3 (`VIBRATO_LUT`, `applyVibrato`, phase tick).
- `config.h` holds all tunables; `DEBUG` Serial output → Task 1 (`config.h`) + Task 3 (DEBUG block).
- `WIRING.md` + `README.md`; `stl/` untouched → Tasks 4, 5 (no task touches `stl/`).
- Audio jack deferred to v2 → out of scope here (spec appendix); no task.
- Verification = compile + manual smoke test → compile step in every code task + Task 6.

**Placeholder scan:** No TBD/TODO/"handle edge cases"; every code step shows complete code; every command shows expected output.

**Type consistency:** `keyHeld`, `pressOrder`, `pressCounter`, `lastFreqWritten`, `vibratoOn`, `vibratoPhase`, `VIBRATO_LUT`, `VIBRATO_STEPS` declared once and used consistently. `activeNote(bool)` signature is identical in Task 2 and Task 3 (Task 2 calls it with `false`; Task 3 with `suppressEnds`). `noteFrequency(int, uint8_t)` and `readOctaveBand()` unchanged between tasks. `config.h` symbols (`KEY_PINS`, `BUZZER_PIN`, `KNOB_PIN`, `NOTE_HZ`, `OCTAVE_BANDS`, `DEBOUNCE_MS`, `COMBO_HOLD_MS`, `VIBRATO_DEPTH_PERMILLE`, `VIBRATO_UPDATE_MS`, `DEBUG`) all referenced with matching names/types.

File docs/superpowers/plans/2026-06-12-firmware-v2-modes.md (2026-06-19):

# Firmware v2 Play Modes Implementation Plan

> **For agentic workers:** REQUIRED SUB-SKILL: Use superpowers:subagent-driven-development (recommended) or superpowers:executing-plans to implement this plan task-by-task. Steps use checkbox (`- [ ]`) syntax for tracking.

**Goal:** Add FX, Song, and Echo modes plus a pentatonic toggle to the 7-key buzzer piano, switched by two-key hold combos.

**Architecture:** A `Mode` enum picks one of four exclusive engines (piano / FX sweep / song player / echo recorder); every engine produces one target frequency (or −1) per `loop()` tick, feeding the existing `lastFreqWritten` dirty-flag `tone()` write. Vibrato and pentatonic are orthogonal toggles applied on that shared path. The v1 single combo generalizes to a table of three `{keyA, keyB, callback}` gestures.

**Tech Stack:** Arduino (ATmega328P, `arduino:avr:nano`), `arduino-cli`. Two-file convention: `config.h` = tunables/data, `child_buzzer.ino` = logic. Song/pointer data in `PROGMEM`.

**Spec:** `docs/superpowers/specs/2026-06-12-firmware-v2-modes-design.md`

**Verification model:** This project has NO automated test harness (per CLAUDE.md). Each task's verify step is:
`arduino-cli compile --fqbn arduino:avr:nano firmware/child_buzzer` → must end with `Sketch uses N bytes` and zero errors. Hardware smoke checks are listed per task and in the final checklist; run them when a board is attached, otherwise rely on the compile gate and code review.

---

### Task 1: Pentatonic table + table-driven combos + suppression mask

**Files:**
- Modify: `firmware/child_buzzer/config.h`
- Modify: `firmware/child_buzzer/child_buzzer.ino`

- [ ] **Step 1: Add pentatonic table and combo key pairs to config.h**

In `config.h`, after the `NOTE_HZ` / `OCTAVE_BANDS` block, add:

```c
// Alternate 7-key mapping: C-major pentatonic spilling into the next octave,
// so random mashing always sounds consonant. Index 0..6 = C D E G A C' D'.
const uint16_t NOTE_HZ_PENTA[7] = { 262, 294, 330, 392, 440, 523, 587 };
```

In the `// ---- Timing ----` section, after `COMBO_HOLD_MS`, add:

```c
// Two-key hold gestures (hold COMBO_HOLD_MS to fire once per hold).
// Symmetric pairs are the easiest two-finger spans for small hands.
const uint8_t COMBO_VIBRATO_A = 0, COMBO_VIBRATO_B = 6;  // ends: toggle vibrato
const uint8_t COMBO_PENTA_A   = 1, COMBO_PENTA_B   = 5;  // toggle pentatonic
```

- [ ] **Step 2: Replace the single-purpose combo with the table-driven detector in child_buzzer.ino**

Delete the v1 block (the three `comboActive` / `comboFired` / `comboStartMs` globals **and** the whole `updateComboToggle()` function). Add a `pentatonicOn` flag next to `vibratoOn`:

```c
bool     pentatonicOn   = false;
```

Replace the v1 `chirp()` function with a parameterized version plus the two toggle callbacks:

```c
// Two quick beeps as toggle feedback. Briefly blocking (~220 ms) — fine for a
// toy; a combo is being held so no note should be sounding anyway.
void chirp(uint16_t hz1, uint16_t hz2) {
  tone(BUZZER_PIN, hz1); delay(70);
  noTone(BUZZER_PIN);    delay(40);
  tone(BUZZER_PIN, hz2); delay(70);
  noTone(BUZZER_PIN);    delay(40);
  lastFreqWritten = -1;              // force the next loop to re-assert the tone
}

void toggleVibrato()    { vibratoOn    = !vibratoOn;    chirp(1568, 2093); }  // rising
void togglePentatonic() { pentatonicOn = !pentatonicOn; chirp(2093, 1568); }  // falling
```

Below the callbacks, add the combo table and detector (replaces `updateComboToggle`):

```c
// ---- Combo gestures (hold two keys COMBO_HOLD_MS to fire once per hold) ----
struct ComboState {
  uint8_t keyA, keyB;
  void (*onFire)();
  bool active;        // both keys currently held (candidate window)
  bool fired;         // already fired during this hold
  uint32_t startMs;
};

const uint8_t COMBO_COUNT = 2;
ComboState combos[COMBO_COUNT] = {
  { COMBO_VIBRATO_A, COMBO_VIBRATO_B, toggleVibrato,    false, false, 0 },
  { COMBO_PENTA_A,   COMBO_PENTA_B,   togglePentatonic, false, false, 0 },
};

void updateCombos(uint32_t now) {
  for (uint8_t c = 0; c < COMBO_COUNT; c++) {
    ComboState &s = combos[c];
    bool both = keyHeld[s.keyA] && keyHeld[s.keyB];
    if (both) {
      if (!s.active) {
        s.active = true;
        s.fired = false;
        s.startMs = now;
      } else if (!s.fired && now - s.startMs >= COMBO_HOLD_MS) {
        s.fired = true;
        s.onFire();
      }
    } else {
      s.active = false;
      s.fired = false;
    }
  }
}

// Bitmask of keys to mute because they are part of a currently-held combo.
uint8_t comboSuppressMask() {
  uint8_t mask = 0;
  for (uint8_t c = 0; c < COMBO_COUNT; c++) {
    if (keyHeld[combos[c].keyA] && keyHeld[combos[c].keyB]) {
      mask |= (uint8_t)((1 << combos[c].keyA) | (1 << combos[c].keyB));
    }
  }
  return mask;
}
```

- [ ] **Step 3: Switch activeNote() to a suppression mask and noteFrequency() to table select**

Replace `activeNote(bool suppressEnds)` with:

```c
// Most-recently-pressed key still held (0..6), or -1 if none.
// Keys whose bit is set in suppressMask are ignored (held combo pairs).
int activeNote(uint8_t suppressMask) {
  int best = -1;
  uint32_t bestOrder = 0;
  for (uint8_t i = 0; i < 7; i++) {
    if (!keyHeld[i]) continue;
    if ((suppressMask >> i) & 1) continue;
    if (pressOrder[i] > bestOrder) {
      bestOrder = pressOrder[i];
      best = i;
    }
  }
  return best;
}
```

Replace `noteFrequency()` with:

```c
// Frequency for a note index at an octave band (doubling per band; exact).
// The pentatonic toggle swaps which 7-entry table the keys map to.
uint16_t noteFrequency(int noteIndex, uint8_t band) {
  const uint16_t *table = pentatonicOn ? NOTE_HZ_PENTA : NOTE_HZ;
  return (uint16_t)(table[noteIndex] << band);
}
```

- [ ] **Step 4: Update loop() and the DEBUG print**

In `loop()`, replace:

```c
  updateComboToggle(now);
```
with:
```c
  updateCombos(now);
```

and replace:

```c
  bool suppressEnds = (keyHeld[0] && keyHeld[6]);
  int note = activeNote(suppressEnds);
```
with:
```c
  uint8_t suppress = comboSuppressMask();
  int note = activeNote(suppress);
```

In the `#if DEBUG` block, extend the line with the pentatonic flag (before the `vib` print):

```c
    Serial.print(F(" penta=")); Serial.print(pentatonicOn ? 1 : 0);
```

- [ ] **Step 5: Compile**

Run: `arduino-cli compile --fqbn arduino:avr:nano firmware/child_buzzer`
Expected: success, `Sketch uses ... bytes`. Fix any errors before committing.

- [ ] **Step 6: Commit**

```bash
git add firmware/child_buzzer/config.h firmware/child_buzzer/child_buzzer.ino
git commit -m "feat(fw): table-driven combos + pentatonic scale toggle (keys 1+5)"
```

Hardware smoke check (when board attached): hold keys 1+5 → falling chirp, keys now play pentatonic; hold again → rising? No — falling chirp both ways (it signals "pentatonic toggled"); keys return to major. Vibrato combo 0+6 unchanged.

---

### Task 2: Mode state machine + mode-cycle combo (keys 2+4)

**Files:**
- Modify: `firmware/child_buzzer/config.h`
- Modify: `firmware/child_buzzer/child_buzzer.ino`

- [ ] **Step 1: Add mode tunables to config.h**

After the combo-pair constants, add:

```c
const uint8_t COMBO_MODE_A = 2, COMBO_MODE_B = 4;        // cycle play mode

// ---- Modes ----
// Entering mode k is announced with k+1 beeps (1 = piano .. 4 = echo).
const uint16_t MODE_BEEP_HZ     = 1047;  // C6
const uint8_t  MODE_BEEP_MS     = 60;
const uint8_t  MODE_BEEP_GAP_MS = 70;
```

- [ ] **Step 2: Add the Mode enum, cycle handler, and engine reset to child_buzzer.ino**

Near the top (after the pentatonic flag), add:

```c
// ---- Play mode ----
enum Mode : uint8_t { MODE_PIANO = 0, MODE_FX, MODE_SONG, MODE_ECHO, MODE_COUNT };
uint8_t  mode = MODE_PIANO;
```

After `togglePentatonic()`, add:

```c
// Stop all mode engines and drop transient state. Extended as engines land
// (FX in Task 3, song in Task 4, echo in Task 5).
void resetEngines() {
}

// k+1 announce beeps. Blocking (<= ~520 ms) like chirp(); acceptable for a toy.
void announceMode() {
  for (uint8_t i = 0; i <= mode; i++) {
    tone(BUZZER_PIN, MODE_BEEP_HZ); delay(MODE_BEEP_MS);
    noTone(BUZZER_PIN);             delay(MODE_BEEP_GAP_MS);
  }
  lastFreqWritten = -1;
}

void cycleMode() {
  mode = (uint8_t)((mode + 1) % MODE_COUNT);
  resetEngines();
  announceMode();
}
```

Extend the combo table to three entries:

```c
const uint8_t COMBO_COUNT = 3;
ComboState combos[COMBO_COUNT] = {
  { COMBO_VIBRATO_A, COMBO_VIBRATO_B, toggleVibrato,    false, false, 0 },
  { COMBO_PENTA_A,   COMBO_PENTA_B,   togglePentatonic, false, false, 0 },
  { COMBO_MODE_A,    COMBO_MODE_B,    cycleMode,        false, false, 0 },
};
```

- [ ] **Step 3: Restructure loop() into the mode dispatch**

Replace the frequency-computation part of `loop()` (everything between `updateCombos(now);` and the `freq != lastFreqWritten` write, exclusive) with:

```c
  uint8_t suppress = comboSuppressMask();

  // Advance the vibrato wobble on its own tick.
  if (vibratoOn && (now - lastVibratoMs >= VIBRATO_UPDATE_MS)) {
    lastVibratoMs = now;
    vibratoPhase = (vibratoPhase + 1) % VIBRATO_STEPS;
  }

  int note = activeNote(suppress);
  uint8_t band = readOctaveBand();

  // Each mode engine answers one question: what frequency right now (-1 = silence)?
  int freq = -1;
  switch (mode) {
    case MODE_PIANO:
      if (note >= 0) freq = noteFrequency(note, band);
      break;
    case MODE_FX:    // engine lands in Task 3
    case MODE_SONG:  // engine lands in Task 4
    case MODE_ECHO:  // engine lands in Task 5
    default:
      break;
  }

  // Vibrato layers over every mode's output.
  if (freq > 0 && vibratoOn) freq = applyVibrato((uint16_t)freq);
```

(The existing `if (freq != lastFreqWritten) { ... }` write stays unchanged below this.)

- [ ] **Step 4: Add mode to the DEBUG print**

In the `#if DEBUG` block, add at the start of the printed line:

```c
    Serial.print(F("mode=")); Serial.print(mode);
    Serial.print(F(" "));
```

- [ ] **Step 5: Compile**

Run: `arduino-cli compile --fqbn arduino:avr:nano firmware/child_buzzer`
Expected: success.

- [ ] **Step 6: Commit**

```bash
git add firmware/child_buzzer/config.h firmware/child_buzzer/child_buzzer.ino
git commit -m "feat(fw): mode state machine + 2+4 mode-cycle combo with beep announce"
```

Hardware smoke check: hold 2+4 → 2 beeps, keys silent (FX stub); cycle 3 more times → 3 beeps, 4 beeps, 1 beep back to piano.

---

### Task 3: FX mode (generic non-blocking sweep engine)

**Files:**
- Modify: `firmware/child_buzzer/config.h`
- Modify: `firmware/child_buzzer/child_buzzer.ino`

- [ ] **Step 1: Add FX definitions to config.h**

After the mode-beep constants, add:

```c
// ---- FX mode ----
// Every effect is one parameter row driven by a shared sweep engine:
//   FX_ONCE     sweep start->end once, then silence until re-press
//   FX_LOOP     sweep start->end, snap back to start, repeat
//   FX_PINGPONG bounce between start and end
//   FX_RETRIG   like FX_ONCE but restarts after FX_RETRIG_GAP_MS while held
enum FxBehavior : uint8_t { FX_ONCE, FX_LOOP, FX_PINGPONG, FX_RETRIG };

struct FxDef {
  uint16_t startHz, endHz;
  uint16_t stepHz;     // size of each pitch step
  uint8_t  stepMs;     // time between steps
  uint8_t  behavior;   // FxBehavior
};

const uint16_t FX_RETRIG_GAP_MS = 180;  // pause between bird chirps

const FxDef FX_DEFS[7] = {
  {  600, 1200,    8,  10, FX_PINGPONG },  // key 0: siren — slow rise/fall wail
  { 2500,  300,  110,   5, FX_ONCE     },  // key 1: laser zap — fast dive
  {  250, 1800,   20,   8, FX_ONCE     },  // key 2: slide whistle — long rise
  {  880, 1100,   44,   9, FX_PINGPONG },  // key 3: UFO warble — narrow fast wobble
  {  800, 1000,  200, 250, FX_PINGPONG },  // key 4: alarm — hard two-tone
  { 2000, 3200,  150,   6, FX_RETRIG   },  // key 5: bird — short rising chirps
  {  400, 2200,  450,  35, FX_LOOP     },  // key 6: robot babble — coarse climbing steps
};
```

- [ ] **Step 2: Add the FX engine to child_buzzer.ino**

After `applyVibrato()`, add:

```c
// ---- FX engine (MODE_FX) ----
int8_t   fxKey = -1;       // key whose effect is running; -1 = idle
uint16_t fxHz = 0;
int8_t   fxDir = 1;        // +1 stepping up, -1 stepping down
bool     fxDone = false;   // FX_ONCE finished / FX_RETRIG waiting out its gap
uint32_t fxNextMs = 0;     // next step time; retrigger time while fxDone

void fxStart(uint8_t key, uint32_t now) {
  fxKey  = (int8_t)key;
  fxHz   = FX_DEFS[key].startHz;
  fxDir  = (FX_DEFS[key].endHz >= FX_DEFS[key].startHz) ? 1 : -1;
  fxDone = false;
  fxNextMs = now + FX_DEFS[key].stepMs;
}

// FX frequency for this tick (-1 = silence). activeKey is last-pressed-wins.
int fxTick(int activeKey, uint32_t now) {
  if (activeKey < 0) {       // releasing silences immediately
    fxKey = -1;
    return -1;
  }
  if (activeKey != fxKey) fxStart((uint8_t)activeKey, now);

  const FxDef &d = FX_DEFS[fxKey];
  if (fxDone) {
    if (d.behavior == FX_RETRIG && now >= fxNextMs) {
      fxStart((uint8_t)fxKey, now);
    } else {
      return -1;
    }
  }

  if (now >= fxNextMs) {
    fxNextMs = now + d.stepMs;
    int32_t lo = min(d.startHz, d.endHz);
    int32_t hi = max(d.startHz, d.endHz);
    int32_t next = (int32_t)fxHz + (int32_t)fxDir * (int32_t)d.stepHz;
    if (next < lo || next > hi) {
      switch (d.behavior) {
        case FX_ONCE:
        case FX_RETRIG:
          fxHz = d.endHz;
          fxDone = true;
          fxNextMs = now + FX_RETRIG_GAP_MS;  // only consulted by FX_RETRIG
          break;
        case FX_LOOP:
          fxHz = d.startHz;
          break;
        case FX_PINGPONG:
          fxDir = (int8_t)-fxDir;
          next = (int32_t)fxHz + (int32_t)fxDir * (int32_t)d.stepHz;
          fxHz = (uint16_t)constrain(next, lo, hi);
          break;
      }
    } else {
      fxHz = (uint16_t)next;
    }
  }
  return (int)fxHz;
}
```

- [ ] **Step 3: Wire FX into resetEngines() and the loop dispatch**

In `resetEngines()`, add:

```c
  fxKey = -1;
  fxDone = false;
```

In the `loop()` switch, replace the `case MODE_FX:` stub line with:

```c
    case MODE_FX:
      freq = fxTick(note, now);
      break;
```

(Keep the `MODE_SONG` / `MODE_ECHO` stub cases.)

- [ ] **Step 4: Compile**

Run: `arduino-cli compile --fqbn arduino:avr:nano firmware/child_buzzer`
Expected: success.

- [ ] **Step 5: Commit**

```bash
git add firmware/child_buzzer/config.h firmware/child_buzzer/child_buzzer.ino
git commit -m "feat(fw): FX mode — 7 effects on a shared non-blocking sweep engine"
```

Hardware smoke check: cycle to FX (2 beeps). Key 0 wails like a siren while held; key 1 zaps once per press; key 5 chirps repeatedly while held; releasing any key silences instantly.

---

### Task 4: Song mode (PROGMEM melodies, knob = tempo)

**Files:**
- Modify: `firmware/child_buzzer/config.h`
- Modify: `firmware/child_buzzer/child_buzzer.ino`

- [ ] **Step 1: Add song encoding, tunables, and the seven melodies to config.h**

After the FX block, add:

```c
// ---- Song mode ----
// A song is a PROGMEM byte stream of {note, duration} pairs.
//   note byte: low 3 bits = scale degree 0..6 into NOTE_HZ (always the major
//              table), bits 3-4 = absolute octave band 0..3.
//   duration:  length in ticks; the knob scales tick length (tempo).
// Special note bytes: rest, low stomp ("boom"), short high hit ("cha").
#define SN(deg, oct) ((uint8_t)((deg) | ((oct) << 3)))
const uint8_t  SONG_REST = 0x7F;
const uint8_t  SONG_THUD = 0x7E;
const uint8_t  SONG_CLAP = 0x7D;
const uint16_t SONG_THUD_HZ = 90;
const uint16_t SONG_CLAP_HZ = 1568;

const uint16_t SONG_TICK_MS_SLOW = 350;  // knob fully left
const uint16_t SONG_TICK_MS_FAST = 110;  // knob fully right
const uint8_t  SONG_GAP_MS = 25;         // articulation gap so repeated notes don't slur

// Key 0: Twinkle Twinkle Little Star (first verse)
const uint8_t SONG_TWINKLE[] PROGMEM = {
  SN(0,1),2, SN(0,1),2, SN(4,1),2, SN(4,1),2, SN(5,1),2, SN(5,1),2, SN(4,1),4,
  SN(3,1),2, SN(3,1),2, SN(2,1),2, SN(2,1),2, SN(1,1),2, SN(1,1),2, SN(0,1),4,
};

// Key 1: Mary Had a Little Lamb
const uint8_t SONG_MARY[] PROGMEM = {
  SN(2,1),2, SN(1,1),2, SN(0,1),2, SN(1,1),2, SN(2,1),2, SN(2,1),2, SN(2,1),4,
  SN(1,1),2, SN(1,1),2, SN(1,1),4, SN(2,1),2, SN(4,1),2, SN(4,1),4,
  SN(2,1),2, SN(1,1),2, SN(0,1),2, SN(1,1),2, SN(2,1),2, SN(2,1),2, SN(2,1),2, SN(2,1),2,
  SN(1,1),2, SN(1,1),2, SN(2,1),2, SN(1,1),2, SN(0,1),8,
};

// Key 2: Ode to Joy (main theme)
const uint8_t SONG_ODE[] PROGMEM = {
  SN(2,1),2, SN(2,1),2, SN(3,1),2, SN(4,1),2, SN(4,1),2, SN(3,1),2, SN(2,1),2, SN(1,1),2,
  SN(0,1),2, SN(0,1),2, SN(1,1),2, SN(2,1),2, SN(2,1),3, SN(1,1),1, SN(1,1),4,
  SN(2,1),2, SN(2,1),2, SN(3,1),2, SN(4,1),2, SN(4,1),2, SN(3,1),2, SN(2,1),2, SN(1,1),2,
  SN(0,1),2, SN(0,1),2, SN(1,1),2, SN(2,1),2, SN(1,1),3, SN(0,1),1, SN(0,1),4,
};

// Key 3: London Bridge
const uint8_t SONG_LONDON[] PROGMEM = {
  SN(4,1),3, SN(5,1),1, SN(4,1),2, SN(3,1),2, SN(2,1),2, SN(3,1),2, SN(4,1),4,
  SN(1,1),2, SN(2,1),2, SN(3,1),4, SN(2,1),2, SN(3,1),2, SN(4,1),4,
  SN(4,1),3, SN(5,1),1, SN(4,1),2, SN(3,1),2, SN(2,1),2, SN(3,1),2, SN(4,1),4,
  SN(1,1),4, SN(4,1),4, SN(2,1),2, SN(0,1),6,
};

// Key 4: Frere Jacques
const uint8_t SONG_FRERE[] PROGMEM = {
  SN(0,1),2, SN(1,1),2, SN(2,1),2, SN(0,1),2,  SN(0,1),2, SN(1,1),2, SN(2,1),2, SN(0,1),2,
  SN(2,1),2, SN(3,1),2, SN(4,1),4,             SN(2,1),2, SN(3,1),2, SN(4,1),4,
  SN(4,1),1, SN(5,1),1, SN(4,1),1, SN(3,1),1,  SN(2,1),2, SN(0,1),2,
  SN(4,1),1, SN(5,1),1, SN(4,1),1, SN(3,1),1,  SN(2,1),2, SN(0,1),2,
  SN(0,1),2, SN(4,0),2, SN(0,1),4,             SN(0,1),2, SN(4,0),2, SN(0,1),4,
};

// Key 5: classic hard-rock four-note riff, transposed to B so the 0/+3/+5/+6
// semitone shape lands entirely on white keys: B-D-E | B-D-F-E | B-D-E | D-B)
const uint8_t SONG_RIFF[] PROGMEM = {
  SN(6,0),2, SN(1,1),2, SN(2,1),3, SONG_REST,1,
  SN(6,0),2, SN(1,1),2, SN(3,1),1, SN(2,1),4, SONG_REST,2,
  SN(6,0),2, SN(1,1),2, SN(2,1),3, SONG_REST,1,
  SN(1,1),2, SN(6,0),6,
};

// Key 6: stadium stomp-stomp-clap + chant hook
const uint8_t SONG_STOMP[] PROGMEM = {
  SONG_THUD,2, SONG_THUD,2, SONG_CLAP,2, SONG_REST,2,
  SONG_THUD,2, SONG_THUD,2, SONG_CLAP,2, SONG_REST,2,
  SN(2,1),2, SN(2,1),2, SN(1,1),2, SN(1,1),2, SN(0,1),3, SONG_REST,1, SN(0,1),4,
  SONG_THUD,2, SONG_THUD,2, SONG_CLAP,2, SONG_REST,2,
  SONG_THUD,2, SONG_THUD,2, SONG_CLAP,2, SONG_REST,2,
};

const uint8_t* const SONGS[7] PROGMEM = {
  SONG_TWINKLE, SONG_MARY, SONG_ODE, SONG_LONDON, SONG_FRERE, SONG_RIFF, SONG_STOMP,
};
const uint8_t SONG_LEN[7] = {  // number of {note, duration} pairs per song
  sizeof(SONG_TWINKLE) / 2, sizeof(SONG_MARY) / 2,  sizeof(SONG_ODE) / 2,
  sizeof(SONG_LONDON) / 2,  sizeof(SONG_FRERE) / 2, sizeof(SONG_RIFF) / 2,
  sizeof(SONG_STOMP) / 2,
};
```

- [ ] **Step 2: Add the song player to child_buzzer.ino**

After the FX engine, add:

```c
// ---- Song player (MODE_SONG) ----
int8_t   songKey = -1;          // -1 = stopped
uint8_t  songPos = 0;           // current {note,duration} pair
bool     songInGap = false;     // articulation gap at the end of a note
uint16_t songFreq = 0;          // 0 = rest
uint32_t songPhaseEndMs = 0;    // end of the current sound/gap phase
uint32_t songLastStamp = 0;     // pressCounter baseline for new-press detection

// Newest key pressed since the last call (-1 = none); suppressed keys ignored.
int songTakeNewPress(uint8_t suppressMask) {
  int best = -1;
  uint32_t bestOrder = songLastStamp;
  for (uint8_t i = 0; i < 7; i++) {
    if ((suppressMask >> i) & 1) continue;
    if (keyHeld[i] && pressOrder[i] > bestOrder) {
      bestOrder = pressOrder[i];
      best = i;
    }
  }
  if (best >= 0) songLastStamp = bestOrder;
  return best;
}

// Knob position -> tick length (left = slow, right = fast).
uint16_t songTickMs() {
  int raw = analogRead(KNOB_PIN);  // 0..1023
  return (uint16_t)(SONG_TICK_MS_SLOW
                    - (uint32_t)raw * (SONG_TICK_MS_SLOW - SONG_TICK_MS_FAST) / 1024);
}

uint16_t songNoteHz(uint8_t noteByte) {
  if (noteByte == SONG_REST) return 0;
  if (noteByte == SONG_THUD) return SONG_THUD_HZ;
  if (noteByte == SONG_CLAP) return SONG_CLAP_HZ;
  uint8_t deg = noteByte & 0x07;
  uint8_t oct = (noteByte >> 3) & 0x03;
  return (uint16_t)(NOTE_HZ[deg] << oct);  // songs always use the major table
}

void songLoadEvent(uint32_t now) {
  const uint8_t *song = (const uint8_t *)pgm_read_ptr(&SONGS[songKey]);
  uint8_t noteByte = pgm_read_byte(song + 2 * songPos);
  uint8_t durTicks = pgm_read_byte(song + 2 * songPos + 1);
  songFreq = songNoteHz(noteByte);
  uint32_t durMs = (uint32_t)durTicks * songTickMs();
  songInGap = false;
  songPhaseEndMs = now + (durMs > SONG_GAP_MS ? durMs - SONG_GAP_MS : durMs);
}

void songStart(uint8_t key, uint32_t now) {
  songKey = (int8_t)key;
  songPos = 0;
  songLoadEvent(now);
}

void songStop() {
  songKey = -1;
}

// Song frequency for this tick (-1 = silence). Same key stops, new key switches.
int songTick(uint32_t now, uint8_t suppressMask) {
  int pressed = songTakeNewPress(suppressMask);
  if (pressed >= 0) {
    if (pressed == songKey) songStop();
    else songStart((uint8_t)pressed, now);
  }
  if (songKey < 0) return -1;

  if (now >= songPhaseEndMs) {
    if (!songInGap) {
      songInGap = true;
      songPhaseEndMs = now + SONG_GAP_MS;
    } else {
      songPos++;
      if (songPos >= SONG_LEN[songKey]) {  // played to the end; stop (no loop)
        songStop();
        return -1;
      }
      songLoadEvent(now);
    }
  }
  if (songInGap || songFreq == 0) return -1;
  return (int)songFreq;
}
```

- [ ] **Step 3: Wire the song player into resetEngines() and the loop dispatch**

In `resetEngines()`, add:

```c
  songStop();
  songLastStamp = pressCounter;  // ignore presses from before the mode switch
```

In the `loop()` switch, replace the `case MODE_SONG:` stub line with:

```c
    case MODE_SONG:
      freq = songTick(now, suppress);
      break;
```

- [ ] **Step 4: Compile**

Run: `arduino-cli compile --fqbn arduino:avr:nano firmware/child_buzzer`
Expected: success. Note the flash usage — songs add ~250 bytes of PROGMEM.

- [ ] **Step 5: Commit**

```bash
git add firmware/child_buzzer/config.h firmware/child_buzzer/child_buzzer.ino
git commit -m "feat(fw): song mode — 7 PROGMEM melodies, knob controls tempo"
```

Hardware smoke check: cycle to song mode (3 beeps). Each key starts its melody; same key stops; different key switches; the knob audibly changes tempo; key 5 is a recognizable hard-rock riff; key 6 does boom-boom-cha.

---

### Task 5: Echo mode (record & parrot)

**Files:**
- Modify: `firmware/child_buzzer/config.h`
- Modify: `firmware/child_buzzer/child_buzzer.ino`

- [ ] **Step 1: Add echo tunables to config.h**

After the song block, add:

```c
// ---- Echo mode ----
const uint8_t  ECHO_MAX_EVENTS = 32;     // ~160 B of SRAM (5 B per event)
const uint16_t ECHO_SILENCE_MS = 1500;   // quiet time before the parrot replies
```

- [ ] **Step 2: Add the echo recorder/player to child_buzzer.ino**

After the song player, add:

```c
// ---- Echo recorder/player (MODE_ECHO) ----
struct EchoEvent {
  uint8_t  noteAndBand;  // low 3 bits = note index, bits 3-4 = octave band
  uint16_t durationMs;
  uint16_t gapMs;        // silence before this note
};

EchoEvent echoBuf[ECHO_MAX_EVENTS];
uint8_t   echoCount = 0;
bool      echoPlaying = false;
uint8_t   echoPos = 0;
bool      echoInGap = false;
uint32_t  echoPhaseEndMs = 0;
int8_t    echoLiveNote = -1;        // note currently sounding while recording
uint8_t   echoLiveBand = 0;
uint16_t  echoPendingGapMs = 0;     // gap captured when the live note opened
uint32_t  echoNoteStartMs = 0;
uint32_t  echoSilenceStartMs = 0;   // when the last note ended

void echoReset() {
  echoCount = 0;
  echoPlaying = false;
  echoLiveNote = -1;
}

void echoOpenNote(int note, uint8_t band, uint32_t now) {
  uint32_t gap = (echoCount == 0) ? 0 : (now - echoSilenceStartMs);
  echoPendingGapMs = (uint16_t)min(gap, (uint32_t)65535);
  echoLiveNote = (int8_t)note;
  echoLiveBand = band;
  echoNoteStartMs = now;
}

void echoCloseNote(uint32_t now) {
  if (echoLiveNote < 0) return;
  if (echoCount < ECHO_MAX_EVENTS) {  // buffer full: drop, keep what fits
    uint32_t dur = now - echoNoteStartMs;
    echoBuf[echoCount].noteAndBand = (uint8_t)(echoLiveNote | (echoLiveBand << 3));
    echoBuf[echoCount].durationMs = (uint16_t)min(dur, (uint32_t)65535);
    echoBuf[echoCount].gapMs = echoPendingGapMs;
    echoCount++;
  }
  echoLiveNote = -1;
  echoSilenceStartMs = now;
}

void echoStartPlayback(uint32_t now) {
  echoPlaying = true;
  echoPos = 0;
  echoInGap = false;
  echoPhaseEndMs = now + echoBuf[0].durationMs;
}

// Echo frequency for this tick (-1 = silence). Records live piano playing;
// after ECHO_SILENCE_MS of quiet it parrots the phrase back, then clears.
int echoTick(int note, uint8_t band, uint32_t now) {
  if (echoPlaying) {
    if (note >= 0) {
      echoReset();  // kid interrupted the parrot; fall through to record
    } else {
      if (now >= echoPhaseEndMs) {
        if (echoInGap) {
          echoInGap = false;
          echoPhaseEndMs = now + echoBuf[echoPos].durationMs;
        } else {
          echoPos++;
          if (echoPos >= echoCount) {
            echoReset();
            return -1;
          }
          echoInGap = true;
          echoPhaseEndMs = now + echoBuf[echoPos].gapMs;
        }
      }
      if (echoInGap) return -1;
      uint8_t nb = echoBuf[echoPos].noteAndBand;
      return (int)noteFrequency(nb & 0x07, (nb >> 3) & 0x03);
    }
  }

  // Recording: live piano behavior, transitions logged.
  if (note != echoLiveNote) {
    if (echoLiveNote >= 0) echoCloseNote(now);
    if (note >= 0) echoOpenNote(note, band, now);
  }
  if (note < 0) {
    if (echoCount > 0 && (now - echoSilenceStartMs >= ECHO_SILENCE_MS)) {
      echoStartPlayback(now);
    }
    return -1;
  }
  return (int)noteFrequency(note, band);
}
```

- [ ] **Step 3: Wire echo into resetEngines() and the loop dispatch**

In `resetEngines()`, add:

```c
  echoReset();
```

In the `loop()` switch, replace the `case MODE_ECHO:` stub (and the now-unneeded `default:` fall-through stub block) with:

```c
    case MODE_ECHO:
      freq = echoTick(note, band, now);
      break;
    default:
      break;
```

- [ ] **Step 4: Compile**

Run: `arduino-cli compile --fqbn arduino:avr:nano firmware/child_buzzer`
Expected: success. Check the reported "Global variables use N bytes" — should stay well under 50% of 2048 B.

- [ ] **Step 5: Commit**

```bash
git add firmware/child_buzzer/config.h firmware/child_buzzer/child_buzzer.ino
git commit -m "feat(fw): echo mode — record up to 32 notes, parrot back after silence"
```

Hardware smoke check: cycle to echo (4 beeps). Play a short phrase, wait ~1.5 s → it plays back with the same rhythm, then the toy is ready to record again. Playing during the replay interrupts it and starts a new recording.

---

### Task 6: Docs + final verification

**Files:**
- Modify: `README.md` (play instructions)
- Modify: `CLAUDE.md` (architecture summary)

- [ ] **Step 1: Update README.md play instructions**

In the README's play-instructions section, document the new gestures and modes (adapt wording to the existing README voice):

```markdown
## Modes & gestures

Hold two keys for ~0.6 s to trigger a gesture (the held keys stay silent):

| Keys | Gesture | Feedback |
|------|---------|----------|
| 1 + 7 (ends) | toggle vibrato | rising chirp |
| 2 + 6 | toggle pentatonic scale | falling chirp |
| 3 + 5 | next mode | 1–4 beeps = current mode |

Modes (announced by beep count):

1. **Piano** — the classic 7-key C-major piano; knob = octave.
2. **FX** — each key is a sound effect: siren, laser, slide whistle, UFO,
   alarm, bird, robot.
3. **Songs** — each key plays a melody (Twinkle Twinkle, Mary Had a Little
   Lamb, Ode to Joy, London Bridge, Frère Jacques, a hard-rock riff,
   a stadium stomp-and-chant); knob = tempo; same key stops.
4. **Echo** — play something, pause 1.5 s, and the toy parrots it back.

Vibrato and pentatonic work in every mode.
```

(Note: README speaks in 1-based key numbers for humans; code is 0-based.)

- [ ] **Step 2: Update CLAUDE.md architecture section**

In CLAUDE.md's Architecture section, update the combo bullet to mention the three table-driven combos (0+6 vibrato, 1+5 pentatonic, 2+4 mode cycle) and add one bullet:

```markdown
- **Four exclusive modes** (`Mode` enum: piano / FX / song / echo) cycled by the
  2+4 combo with beep-count announce. Every mode engine returns one frequency
  (or -1) per tick into the shared `lastFreqWritten` dirty-flag `tone()` write;
  vibrato and the pentatonic table-swap layer on top in any mode.
```

- [ ] **Step 3: Final compile + memory check**

Run: `arduino-cli compile --fqbn arduino:avr:nano firmware/child_buzzer`
Expected: success; flash < 80% of 30720 B, globals < 50% of 2048 B. Record the numbers in the commit message.

- [ ] **Step 4: Run the full smoke-test checklist (hardware attached)**

From the spec (`docs/superpowers/specs/2026-06-12-firmware-v2-modes-design.md`, Verification section): items 1–8. If no board is attached, note that flashing + smoke test is pending.

- [ ] **Step 5: Commit**

```bash
git add README.md CLAUDE.md
git commit -m "docs: document v2 modes, combos, and smoke-test results"
```

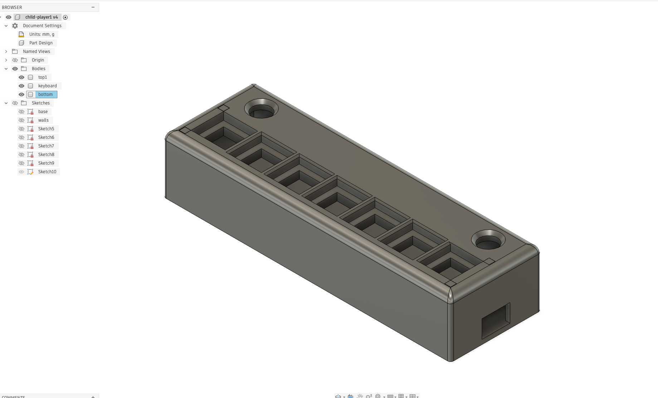
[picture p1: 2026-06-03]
screenshoots/model_v1.png

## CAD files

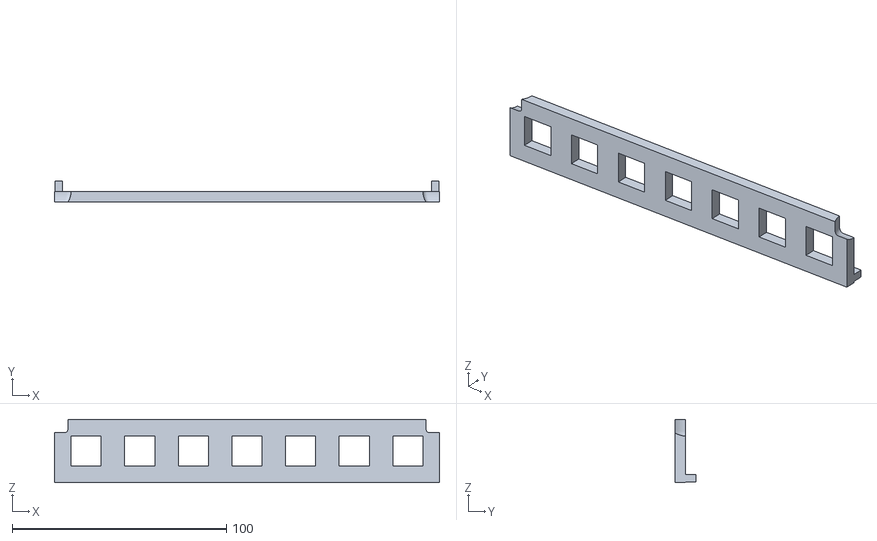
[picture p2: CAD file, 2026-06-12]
stl/keyboard.stl
179.5 x 10.0 x 29.5

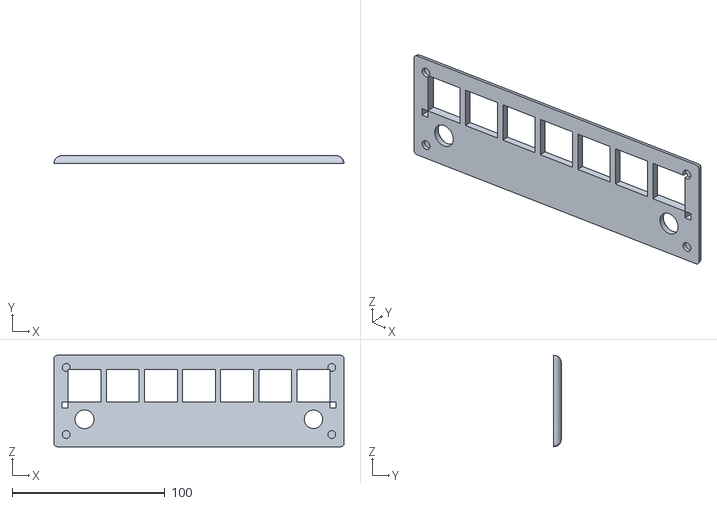
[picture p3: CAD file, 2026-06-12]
stl/top1.stl
190.0 x 5.00 x 60.0

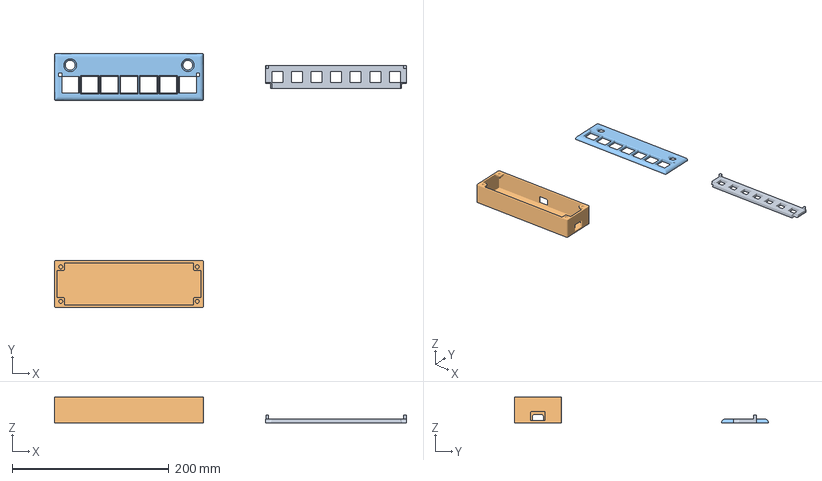
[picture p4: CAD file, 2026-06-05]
stl/player1.3mf
448.8 x 324.0 x 33.0 mm
keyboard.stl
bottom.stl
top1.stl

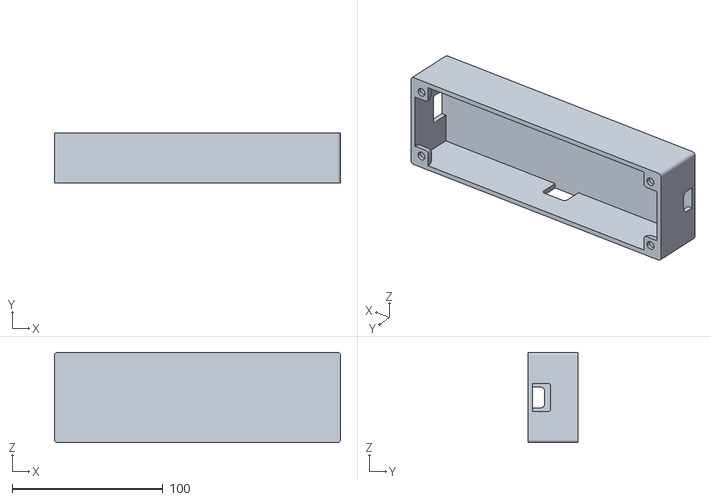
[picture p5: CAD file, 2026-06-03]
stl/bottom.stl
190.0 x 33.0 x 60.0

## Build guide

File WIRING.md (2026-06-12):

# Wiring — Child Buzzer Synth (v1)

Board: Arduino Nano. All switches use the internal pull-ups, so a pressed key
just connects its pin to GND (reads LOW). No external resistors needed.

## Keyboard switches (7)

| Key | Note | Nano pin | Switch wiring |
|-----|---|---|---|
| 1 (lowest)  | C | D2 | one leg → D2, other leg → GND |
| 2 | D | D3 | one leg → D3, other leg → GND |
| 3 | E | D4 | one leg → D4, other leg → GND |
| 4 | F | D5 | one leg → D5, other leg → GND |
| 5 | G | D6 | one leg → D6, other leg → GND |
| 6 | A | D7 | one leg → D7, other leg → GND |
| 7 (highest) | B | D8 | one leg → D8, other leg → GND |

Tie every switch's "other leg" to a shared GND rail.

## KY-006 passive buzzer

| KY-006 pin | Connect to |
|---|---|
| S (signal) | D9 |
| − (GND) | GND |
| centre pin (labelled `+` or `VCC`) | leave unconnected (passive module; varies by board) |

## Rotary angle sensor (potentiometer) — octave knob

| Pot pin | Connect to |
|---|---|
| one outer leg | 5V |
| other outer leg | GND |
| wiper (middle)  | A0 |

If the knob shifts pitch the "wrong" way, swap the two outer legs (5V ↔ GND).

## Power & ground

Power the Nano over USB (or regulated 5V). All grounds (switches, buzzer, pot)
share one common GND.

## How to play

- Press a key → its note sounds while held (one note at a time, newest wins).
- Turn the knob → shifts all keys across 4 octaves (deep ↔ squeaky) in Piano
  and Echo modes; sets the tempo in Songs mode.
- Two-key hold gestures (~0.6 s): lowest + highest → vibrato (rising chirp);
  2nd + 6th → pentatonic scale (falling chirp); 3rd + 5th → next mode,
  announced by 1–4 beeps (Piano / FX / Songs / Echo). Full mode guide is in
  README.md ("Modes & gestures").

## Troubleshooting

- Keys register (serial `DEBUG` shows `note`/`freq`) but no sound → check the
  KY-006 S and − connections; the joint is known to go intermittent after
  enclosure reassembly. Consider soldering + strain relief.

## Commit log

2026-06-03 Initial commit: 3D enclosure models and render for child buzzer synth
    [bottom.stl, keyboard.stl, player1.3mf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]
2026-06-04 Defer audio jack to v2; scope spec to buzzer-only v1 (jack design+BOM kept in appendix)
2026-06-04 feat(fw): scaffold sketch with pin setup and tunable config.h
2026-06-04 feat(fw): playable mono piano — debounced keys, last-pressed-wins, octave knob
2026-06-04 feat(fw): add vibrato wobble + squeeze-both-ends toggle with chirp + DEBUG
    [child_buzzer.ino]
2026-06-04 docs: add pin-by-pin wiring guide
2026-06-04 refactor(fw): move vibrato LUT/steps to config.h; clarify KY-006 centre pin in wiring
    [child_buzzer.ino, config.h]
2026-06-05 chore: enable DEBUG serial build + update player1 print model
    - config.h: DEBUG 1 (serial state output @115200 for hardware bring-up)
    - stl/player1.3mf: updated 3D print model
    [player1.3mf]
2026-06-12 stl: update keyboard and top1 enclosure models
    [keyboard.stl, top1.stl]
2026-06-12 fix(fw): refresh now after blocking combo callbacks; harden freq=0 silence hole
    [child_buzzer.ino]
2026-06-12 feat(fw): FX mode — 7 effects on a shared non-blocking sweep engine
2026-06-12 fix(fw): wraparound-safe FX step timing; document FX table constraints
    [child_buzzer.ino, config.h]
2026-06-12 feat(fw): song mode — 7 PROGMEM melodies, knob controls tempo
2026-06-12 fix(fw): drop suppressed combo presses in song mode; tempo endpoint + doc polish
    [child_buzzer.ino, config.h]
2026-06-12 feat(fw): echo mode — record up to 32 notes, parrot back after silence
2026-06-12 fix(fw): drop combo-entry junk notes from echo recording; debug + comments
    [child_buzzer.ino]
2026-06-12 fix(fw): cancel song started by a combo gesture's first finger
    [child_buzzer.ino]
2026-06-12 docs: pin old-bootloader FQBN for this board in CLAUDE.md
2026-06-12 docs: mark v2 spec verified; old-bootloader flash example; WIRING gestures + troubleshooting
2026-06-19 feat(fw): replace London Bridge & Frère Jacques with Let It Go (hook + full)
    Song keys 3 & 4 now play "Let It Go" (Frozen): key 3 is the chorus hook,
    key 4 is the full verse → pre-chorus → chorus arrangement. Diatonic
    white-key reduction (C major / A minor) to fit the no-accidentals song
    format. Update README and v2 modes spec to match; add design spec.
    Compiles at 8214 bytes (26% flash), 667 bytes RAM.
    Claude-Session: https://claude.ai/code/session_018opmnz7x4fsnnZdWy8vpn3
    [config.h]
2026-06-19 refactor(fw): de-name song tables (describe music, not titles)
    Rename the three branded song tables to describe their musical character
    instead of their source title, and reword the surrounding comments to match.
    No behavior change — index-based dispatch via SONGS[], identical binary
    (8214 bytes / 26% flash).
    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
